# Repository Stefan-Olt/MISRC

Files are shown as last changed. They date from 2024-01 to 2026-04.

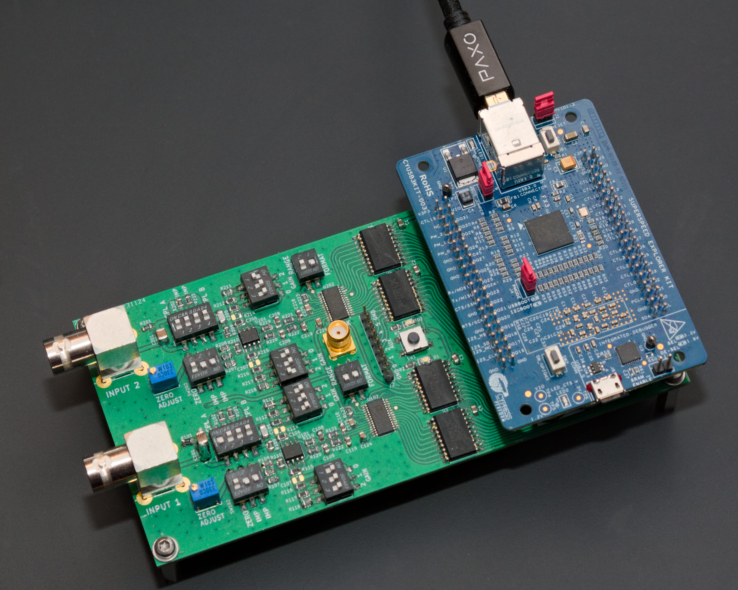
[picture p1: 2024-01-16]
assets/hardware-images/MISRC-v0.0.5-Transparent-Hand-Soldered.jpg

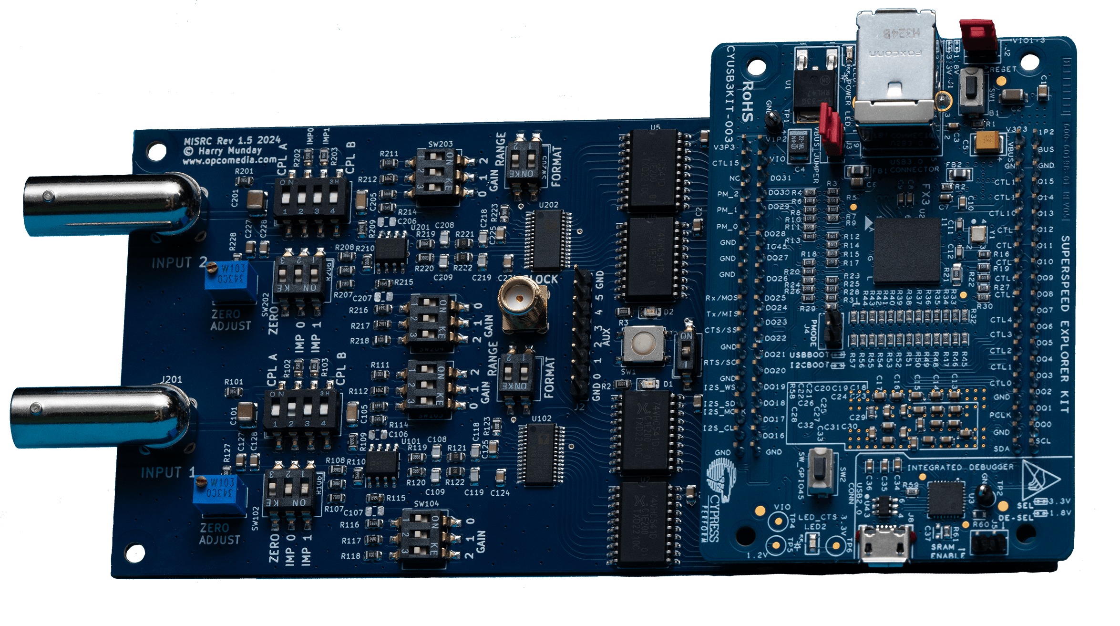
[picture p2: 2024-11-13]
assets/hardware-images/MISRC_v1.5_Sony_ILCE-7RM3_2024.06.07_14.30.14-Small.png

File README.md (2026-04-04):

# MISRC - Multi Input Simultaneous Raw RF Capture

[Hardware](#hardware-features) - [Firmware](#firmware-tang-nano-20k) - [Software](#software) - [Usage example](#capture--usage-example)

<picture>

</picture>

> V1.5 with Tang Nano 20k on the FX3 to Tang Nano 20k adaptor PCB. 

## Description

MISRC is a device to capture two signals at 12-bit and up to 40 MSPS (20 Mhz bandwith) (This could be extended to 80 MSPS in the future) and an additional 8-bit's (2-bit's for v2.5) of binary (auxiliary data) over USB 3.0.

It is intended to capture modulated tape deck RF for software demodulation, but also baseband CVBS/S-Video (Composite) video signals for software decoding, and can be used as a direct stream Oscilloscope but limited to 2vpp input voltage.

The Decode Projects:

- [VHS-Decode](https://github.com/oyvindln/vhs-decode/)
- [HiFi-Decode](https://github.com/oyvindln/vhs-decode/wiki/hifi-decode)
- [CVBS-Decode](https://github.com/oyvindln/vhs-decode/wiki/CVBS-Composite-Decode) 

Provide decoding for a wide range of videotape formats, HiFi audio and even RAW or Baseband composite decoding with free and powerful software time base correction with full post filtering control over the signal processing.

-----------

| Media RF Type | MISRC Support |
| --- | --- |
| Video FM RF | Yes |
| HiFi FM RF | Yes |
| CVBS RF | Yes |
| S-Video RF | Yes |

Possible capture examples:

- Capture 2x CVBS
- Capture 1x S-Video (Y & C)
- Capture Video RF and HiFi RF simultaneously
- Capture Video RF and CVBS simultaneously
- Capture 4ch of 24-bit 48khz audio with AUX pins via integrated or external clock-locked ADCs

> [!NOTE]
> It may be useful for other purposes as well, as it is built as a generic ADC with configurable filtering.

## Hardware features

- Dual ADC / Dual Input (BNC Connectors)
- 6 Extra Aux inputs for audio ADC modules etc
- Two 12-bit 40msps ADCs: [AD9235](https://www.analog.com/media/en/technical-documentation/data-sheets/AD9235.pdf)
- Selectable input gain (8 steps) (using [AD8138](https://www.analog.com/media/en/technical-documentation/data-sheets/ad8138.pdf) op-amp)
- Selectable ADC range (1V or 2V)
- Selectable input impedance (75, 50, 37.5 and 30 ohms)
- DC or AC (pre- or post-termination) coupling
- Zero-adjust to compensate DC offset
- Latching clipping indicator (automatic resetting on v2.5) 
- Clock source selectable: USB PLL (FX3 setup), crystal or external
- Clock output SMA for external devices (In/Out for V2.5)
- Melted PCB Traces

## Costs

> [!TIP]  
> You can support the development and production of the MISRC platform [here](https://github.com/Stefan-Olt/MISRC/wiki/Donations).
- PCB: 20-30USD
- Parts 100-150USD
- Single unit total production cost is currently 260-300USD.
- [Order a V1.5 Development MISRC](https://github.com/Stefan-Olt/MISRC/wiki/Fabrication)

------

> [!NOTE]  
> These are off-shelf PCBs and USB 3.0 devices that you add to the MISRC PCB.

- [Tang Nano 20k](https://s.click.aliexpress.com/e/_DcwBOX3) - buffer / data output over HDMI.
- [MS2130](http://en.macrosilicon.com/info.asp?base_id=2&third_id=75) - [Order Link 1](https://s.click.aliexpress.com/e/_DBaBiOp) / [Order Link 2](https://s.click.aliexpress.com/e/_okDl2Vf) - HDMI raw data stream capture.

> [!TIP]  
> You can order pre-made [adaptor PCBs here](https://ko-fi.com/s/617b72ab2c) for V1.5 boards with the headders for the FX3.  

## Firmware (Tang Nano 20k)

To be able to use the [Tang Nano 20k](https://s.click.aliexpress.com/e/_DcwBOX3) to send data over HDMI, it needs to be flashed once via USB connection:

<details closed>
<summary>Firmware Flashing </summary>
<br>

1. Download the firmare, see [releases](https://github.com/Stefan-Olt/MISRC/releases) for the latest version.

2. Install [openFPGALoader](https://github.com/trabucayre/openFPGALoader)

3. Connect your Tang to a USB 3.0 port via its Type-C, it will need this for 5V power after flashing, but not data from the MISRC.

   Run via terminal inside the firmware directory

       openFPGALoader -b tangnano20k -f hsdaoh_nano20k_misrc.fs

You have flashed your Tang Nano 20k! 

</details>

## Software

Supported operating systems with direct links to the latest release (also available on the [releases tab](https://github.com/Stefan-Olt/MISRC/releases)):

| Operating System  | Minimum supported OS version | Download x86_64 (Intel / AMD) | Download arm64 (Apple Silicon / aarch64) |
| --- | --- | --- | --- |
| Microsoft Windows | 10 (1803) | [misrc_tools-0.5.1-win-x86_64.zip](https://github.com/Stefan-Olt/MISRC/releases/download/misrc_tools-0.5.1/misrc_tools-0.5.1-win-x86_64.zip) | [misrc_tools-0.5.1-win-arm64.zip](https://github.com/Stefan-Olt/MISRC/releases/download/misrc_tools-0.5.1/misrc_tools-0.5.1-win-arm64.zip) |
| Apple macOS | 10.15 | [misrc_tools-0.5.1-macos-intel-x86_64.tar.gz](https://github.com/Stefan-Olt/MISRC/releases/download/misrc_tools-0.5.1/misrc_tools-0.5.1-macos-intel-x86_64.tar.gz) | [misrc_tools-0.5.1-macos-apple-silicon-arm64.tar.gz](https://github.com/Stefan-Olt/MISRC/releases/download/misrc_tools-0.5.1/misrc_tools-0.5.1-macos-apple-silicon-arm64.tar.gz) |
| Linux | libc6 2.35 (Ubuntu 22.04) | [misrc_tools-0.5.1-linux-x86_64.tar.gz](https://github.com/Stefan-Olt/MISRC/releases/download/misrc_tools-0.5.1/misrc_tools-0.5.1-linux-x86_64.tar.gz) | [misrc_tools-0.5.1-linux-arm64.tar.gz](https://github.com/Stefan-Olt/MISRC/releases/download/misrc_tools-0.5.1/misrc_tools-0.5.1-linux-arm64.tar.gz) |

> [!NOTE]  
> The arm64 builds for Windows are untested and considered experimental!

The packages contain two command-line applications, `misrc_capture` and `misrc_extract`. For detailed usage information see the [misrc_tools readme](/misrc_tools/README.md) and the [usage example](#capture--usage-example) down below.

If you want to build the tools yourself, see the instructions in the [misrc_tools readme](/misrc_tools/README.md).

<details closed>
<summary>Install Windows</summary>
<br>

For `misrc_capture` to be able to access the MS2130 capture device, you need to install a special driver:

Firstly download [Zadig](https://zadig.akeo.ie/)

Force the installation of `WinUSB (v6.1.7600.16385)` or `libusb-win32 (v1.2.6.0)` driver on your MS2130/MS2131 adapter, on `interface 0` leave `interface 4` alone. 

```
Interface 0 - USB Video
Interface 4 - HIDDevice
```

</details>

<details closed>
<summary>Install macOS</summary>
<br>

For macOS you do not need to install anything.

- macOS versions 10.15 and 11: You can directly execute `misrc_capture`.
- macOS 12 and later: You have to run `misrc_capture` as root (sudo). This is a new security feature by Apple, there is currently no way to bypass it. 

</details>

<details closed>
<summary>Install Linux</summary>
<br>

If you want to run `misrc_capture` as root, there is no need to install anything on Linux.

But for `misrc_capture` to be able to access the MS2130 capture device without root privilege (sudo), you need to install a udev-rule and add the user that will use `misrc_capture` to the `plugdev`-group.
The pre-build packages contains the script `install-udev-rules.sh`. On execution (double-click the file or run `./install-udev-rules.sh` on the command line) it will install the rule and add the current user to the plugdev group.

</details>

## Capture / Usage example

> [!TIP]  
> Pre-built Binaries is available on the [releases tab](https://github.com/Stefan-Olt/MISRC/releases).

`misrc_capture` is a simple command line interface program to capture from MISRC boards using [hsdaoh](https://github.com/Stefan-Olt/hsdaoh) to which leverages data capture over HDMI with [MS2130](https://s.click.aliexpress.com/e/_DBaBiOp) "U3" cheep HDMI capture cards that have YUV support and full-frame signal acesses. 

Create a folder which you wish to capture inside, open it inside terminal and then run `misrc_capture`.

Example with FLAC compression:
    
    misrc_capture -p -f -l 8 -a video_rf.flac -b hifi_rf.flac 

Example RAW:

    misrc_capture -a video_rf.s16 -b hifi_rf.s16

Example with AUX pins capture ([PCM1802 audio example](https://github.com/Stefan-Olt/MISRC/wiki/PCM-Extract))

    misrc_capture -p -f -l 8 -a video_rf.flac -b hifi_rf.flac -x pcm1802.bin

You can also define its directory path of each RF stream manually: 

    misrc_capture -p -f -l 8 -a /mnt/my_video_storrage/video_rf.flac -b ../../this/is/a/relative/path/hifi_rf.flac

Press <kbd>Ctrl</kbd>+<kbd>C</kbd> to copy and <kbd>Ctrl</kbd>+<kbd>P</kbd> to past your config from a notepad or txt file.

Use <kbd><</kbd>+<kbd>></kbd> to move edit position on the command line to edit the name or command while in terminal and <kbd>Enter</kbd> to run the command.

<kbd>Ctrl</kbd>+<kbd>C</kbd> Will kill the current process, use this to stop the capture manually.

<details closed>

<summary>Usage Arguments:</summary>
<br>

Example:

    misrc_capture -p -f -l 8 -a video_rf.flac -b hifi_rf.flac -x baseband_audio.bin

Usage:

- `-d` device_index (default: 0) (select target MS21xx device for capture)
- `-n` number of samples to read (default: 0, infinite)
- `-t` time to capture (seconds, m:s or h:m:s; -n takes priority, assumes 40msps)
- `-w` overwrite any files without asking
- `-a` ADC A output file (use '-' to write on stdout)  
- `-b` ADC B output file (use '-' to write on stdout)  
- `-x` AUX output file (use '-' to write on stdout)  
- `-r` RAW 32-Bit data output file (use '-' to write on stdout)  
- `-p` pad lower 4 bits of 16 bit output with 0 instead of upper 4
- `-A` suppress clipping messages for ADC A (need to specify -a or -r as well)
- `-B` suppress clipping messages for ADC B (need to specify -a or -r as well)
- `-f` compress ADC output as FLAC  
- `-l` LEVEL set flac compression level (default: 1) 
- `-v` enable verification of flac encoder output  
- `-c` number of flac encoding threads per file (default: auto)

</details>

## Setting Up the MISRC

- Connect your 5V USB-C to the Tang Nano for power. 

- Connect your HDMI cable (copper or fibre) to your Tang Nano for data output to the MS2130 or MS2131. 

- Connect the desired sources to the BNC inputs and select suitable impedance and AC or DC coupling.

> [!NOTE]
> You will want to use 2vpp range rather than 1vpp range to make use of the 12-bits range.

Install [OCENAudio](https://www.ocenaudio.com/) or alternatives like [Audacity](https://www.audacityteam.org/download/) it will see captures as a `40khz 16-bit` file.

Run a 3-second test capture in FLAC, to be automatically reloaded for viewing. 

    misrc_capture -p -f -B -t 3 -a test.flac

Start the capturing process for setting the DC offset then gain:
    
    - Reset clipping LEDs (always on after start or major adjustment) 
    - Increase gain during capture until clipping LED lights up
    - Decrease gain one step and reset clipping LED
    - Repeat for the second channel if in use.

- Stop capture and verify levels are acceptable in your audio DAW and the signal is centred.

Once happy, then do a full test capture to verify. 

> [!CAUTION]
> - NEVER use USB for any other heavy-load task (like external HDD/SSD drives, USB network adaptors, YUV capture devices) during capture. 
> - Do not connect/disconnect any other USB device during capture, a dedicated USB 3.0 to 3.2 Gen 2 card is ideal for dedicated capture stations as it ensures dedicated bandwidth/power if you have other items that require USB.

## Design

MISRC is loosely based on the [Domesday Duplicator (DdD)](https://github.com/simoninns/DomesdayDuplicator) a LaserDisc focused ([ld-decode](https://github.com/happycube/ld-decode)) FM RF Archival device. 

It is built around the AD9235 analogue to digital converter by Analog Devices and is heavily based on the evaluation board circuit given in its datasheet with the AD8138 Op-Amp providing adjustable fixed gain.

The MISRC like the DdD it originally used the [Cypress FX3 SuperSpeed Explorer board](https://www.infineon.com/cms/en/product/evaluation-boards/cyusb3kit-003/) for a USB 3.0 data connection, and using Sigronk for capture, with hopes to not use the DE0 FPGA, this ended with the adoption of the Tang Nano 20k and MS2130 "data over YUV" method being used. 

## License

The hardware, firmware and software is released under different open-source licenses.
You can read the [License here](https://github.com/Stefan-Olt/MISRC/wiki/Licenses)

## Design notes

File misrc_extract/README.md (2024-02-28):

# MISRC extract

Tool to extract the two ADC channels and the AUX data from the raw capture.

## Description

The 2 ADC channels with 12 bit each and the 8 bit AUX data is interleaved into 32 bit words.
This tool will deinterleave the data. For x86_64 (64 bit AMD and Intel processors)
there is handwritten assembly for higher performance using SSE instructions.

## Building

### Linux, macOS, BSD etc.

```
mkdir build
cd build
cmake ..
make
make install
```

### Windows

TBD

## Usage

* Run tool without arguments to see options

## Version History

* 0.3.1
    * Fix: incorrect align could lead to crash (fix by namazso)

* 0.3
    * New: allow extraction of data from single channel capture

* 0.2
    * Fix: signal now with correct polarity
    * Mod: output program name and version
    * New: option to pad lower 4 bits instead of upper 4

* 0.1
    * Initial Release

## License

This project is licensed under the GNU General Public License v3 or later - see the LICENSE file for details

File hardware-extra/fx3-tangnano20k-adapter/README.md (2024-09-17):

# FX3 to Tang Nano 20K Adapter

Passive adapter to use a Tang Nano 20K on MISRC that is designed to connect to a FX3 board.

## Revision 0.0.1
* First hardware build

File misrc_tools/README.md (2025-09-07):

# MISRC tools

## misrc_capture

Tool to capture, extract and compress data from the HDMI input of MS2130 using hsdaoh.

### Description

A MISRC `1.x/2.x` (with Tang Nano 20k setup) will pack the data into an HDMI signal for the MS2130.

`misrc_capture` will disable any procssing on the MS2130 and capture the data using hsdaoh. The data is unpacked in realtime and can be outputted directly into two separate files for the ADCs and a file for the aux data.
For x86_64 (64 bit AMD and Intel processors) there is handwritten assembly for higher performance using SSE instructions.

### Usage

- Run tools without arguments to see all options

Example:

    misrc_capture -p -f -l 8 -a video_rf.flac -b hifi_rf.flac -x aux_baseband_audio.bin

Usage:

- `-d` device_index (default: 0) (select target MS21xx device for capture)
- `-n` number of samples to read (default: 0, infinite)
- `-t` time to capture (seconds, m:s or h:m:s; -n takes priority, assumes 40msps)
- `-w` overwrite any files without asking
- `-a` ADC A output file (use '-' to write on stdout)  
- `-b` ADC B output file (use '-' to write on stdout)  
- `-x` AUX output file (use '-' to write on stdout)  
- `-r` RAW 32-Bit data output file (use '-' to write on stdout)  
- `-p` pad lower 4 bits of 16 bit output with 0 instead of upper 4
- `-A` suppress clipping messages for ADC A (need to specify -a or -r as well)
- `-B` suppress clipping messages for ADC B (need to specify -a or -r as well)
- `-f` compress ADC output as FLAC  
- `-l` LEVEL set flac compression level (default: 1) 
- `-v` enable verification of flac encoder output  
- `-c` number of flac encoding threads per file (default: auto)

## misrc_extract

A simple program for extracting captured raw data into separate files.

### Description

The MISRC has 2 ADC channels with 12-bit's each and the 8-bit's of AUX data is also interleaved into a total of 32 bit words.

This tool will deinterleave the data. 

### Usage

Example:

    misrc_extract -i raw_32-bit_dump.bin -p -a channel_1.s16 -b channel_2.s16 -x aux_data.bin

- `-i` Input file (use '-' to read from stdin)  
- `-a` ADC A output file (use '-' to write on stdout)  
- `-b` ADC B output file (use '-' to write on stdout)  
- `-x` AUX output file (use '-' to write on stdout)  
- `-p` pad lower 4 bits of 16 bit output with 0 instead of upper 4  
- `-s` input is captured as single channel (-b cannot be used)  

## Version History

* 0.5.1
    * Fix: build issue with FFmpeg caused builds without resampling

* 0.5
    * Fix: only capturing AUX, but no RF caused crash
    * Fix: overwrite question would only work for first file
    * New: RF can now be resampled by misrc_capture, resulting in smaller files and faster processing when only a smaller bandwidth is needed
    * New: initial audio support for the upcoming MISRC v2.5

* 0.4
    * Release of new tool: misrc_capture for direct capture from HDMI/MS2130 using hsdaoh
    * Builds for Linux, macOS and Windows (x86_64 and arm64 on all platforms)

* 0.3.1
    * Fix: incorrect align could lead to crash (fix by namazso)

* 0.3
    * New: allow extraction of data from single channel capture
      (Cypress FX3 setup)

* 0.2
    * Fix: signal now with correct polarity
    * Mod: output program name and version
    * New: option to pad lower 4 bits instead of upper 4

* 0.1
    * Initial Release

## Building / Compilation

### Required build tools

- A somewhat modern C compiler
- git (for manual compilation)
- curl (for automatic build script)
- cmake
- nasm (for x86_64 platform)
- meson/ninja (for static builds/automatic compilation)

Installation of build tools:
- macOS using [brew](https://brew.sh/): 

      brew install git curl cmake nasm meson ninja

- Linux (Debian, Ubuntu, Mint) using apt: 

      apt install build-essential git curl cmake nasm meson ninja-build

- Windows (msys2/UCRT64) using pacman: 

      pacman -S git curl mingw-w64-ucrt-x86_64-gcc mingw-w64-ucrt-x86_64-pkg-config mingw-w64-ucrt-x86_64-cmake mingw-w64-ucrt-x86_64-nasm mingw-w64-ucrt-x86_64-meson mingw-w64-ucrt-x86_64-ninja

### Automatic compilation
The script `build/build-static.sh` can be used for bulding a statically linked version.
It will download and compile dependencies. It is used to build the binaries downloadable here.
In case it doesn't work for your needs you can compile misrc_tools manually.

### Dependencies
- [libusb](https://github.com/libusb/libusb)
- [libuvc](https://github.com/libuvc/libuvc) (for Windows cmake fixes use [Steve-m's fork](https://github.com/steve-m/libuvc))
- [hsdaoh](https://github.com/Stefan-Olt/hsdaoh) (the main hsdaoh branch (steve-m) does not have required changes merged, use the linked one!)
- [FLAC](https://github.com/xiph/flac) (optional, v1.5.0 and newer required for multi-threading support)

Installation of FLAC, libusb and libuvc (if available):

- macOS using [brew](https://brew.sh/): 

      brew install flac libusb

- Linux (Debian, Ubuntu, Mint) using apt: 

      apt install libflac-dev libusb-1.0-0-dev libuvc-dev

- Windows (msys2/UCRT64) using pacman: 

      pacman -S mingw-w64-ucrt-x86_64-flac mingw-w64-ucrt-x86_64-libusb

## Manual Build Process

1. Build libuvc (required on Windows and macOS):
   <details closed>
   <summary>macOS (Linux, BSD...)</summary>
   
   ```
   git clone https://github.com/libuvc/libuvc.git
   mkdir libuvc/build && cd libuvc/build
   cmake ../
   make
   sudo make install
   ```
   
   </details>
   <details closed>
   <summary>Windows</summary>
   
   ```
   git clone https://github.com/steve-m/libuvc.git
   mkdir libuvc/build && cd libuvc/build
   cmake ../ -DCMAKE_INSTALL_PREFIX:PATH=/mingw64
   cmake --build .
   cmake --install .
   ```
   
   </details>

2. Build hsdaoh
   <details closed>
   <summary>Linux, macOS, BSD...</summary>
   
   ```
   git clone https://github.com/Stefan-Olt/hsdaoh.git
   mkdir hsdaoh/build
   cd hsdaoh/build
   cmake ../ -DINSTALL_UDEV_RULES=ON
   make
   sudo make install
   sudo ldconfig
   ```
   
   </details>
   <details closed>
   <summary>Windows</summary>
   
   ```
   git clone https://github.com/Stefan-Olt/hsdaoh.git
   mkdir hsdaoh/build && cd hsdaoh/build
   cmake ../ -DCMAKE_INSTALL_PREFIX:PATH=/mingw64
   cmake --build .
   cmake --install .
   ```
   
   </details>

3. Build misrc_tools
   <details closed>
   <summary>Linux, macOS, BSD...</summary>
   
   ```
   git clone https://github.com/Stefan-Olt/MISRC.git
   cd ./MISRC/misrc_tools
   mkdir build
   cd build
   cmake ../
   make
   sudo make install
   ```
   
   </details>
   <details closed>
   <summary>Windows</summary>
   
   ```
   git clone https://github.com/Stefan-Olt/MISRC.git
   cd ./MISRC/misrc_tools
   mkdir build
   cd build
   cmake ../ -DCMAKE_INSTALL_PREFIX:PATH=/mingw64
   cmake --build .
   cmake --install .
   ```
   
   </details>

## License

This project is licensed under the GNU General Public License v3 or later - see the LICENSE file for details.

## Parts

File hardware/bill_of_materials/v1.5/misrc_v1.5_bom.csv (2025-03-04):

Designator | Qty | Value | Package/Footprint | Type | Manufacturer Part Number | BOM Notes | Notes
C1, C12, C13, C2, C20, C21, C22, C23, C24, C29, C3, C30, C31, C4, C5, C7 | 16 | 1µf | C_0805_2012Metric | SMD | KGM21AR71H105KU | Exact Part Not Required
C10, C17, C18, C11, C16, C19, C6 | 7 | 470µf | CP_Radial_Flat_D8.0mm_P3.50mm | THT | UHV1C471MPD | Exact Part Not Required | Lay Flat, Not Vertical for pin headder clearence.
C101, C201 | 2 | 100µf | C_1210_3225Metric | SMD | EMK325ABJ107MM-T | Exact Part Not Required
C102, C110, C117, C202, C210, C217 | 6 | 10µf | C_1210_3225Metric | SMD | CA45-A-16V-10μF-K（C185774) | Exact Part Not Required
C103, C112, C113, C115, C120, C122, C123, C124, C125, C126, C14, C15, C203, C212, C213, C215, C220, C222, C223, C224, C225, C226, C26, C9 | 24 | 100nf | C_0805_2012Metric | SMD | C0805C104K4RACTU | Exact Part Not Required
C104, C111, C114, C116, C121, C128, C204, C211, C214, C216, C221, C228, C27 | 13 | 1nf | C_0805_2012Metric | SMD | C0805C102J5GACTU | Exact Part Not Required
C105, C205 | 2 | 470nf | C_1206_3216Metric | SMD | CC1206KKX7R9BB474 | Exact Part Not Required
C106, C107, C206, C207 | 4 | 1pf | C_0805_2012Metric | SMD | C0805C109C2GACTU | Exact Part Not Required | DNP
C108, C109, C208, C209 | 4 | 82pf | C_0805_2012Metric | SMD | C0805C820J5GACTU | Exact Part Not Required
C118, C119, C218, C219 | 4 | 15pf | C_0805_2012Metric | SMD | C0805X150J5GACTU | Exact Part Not Required
C127, C227, C25, C28, C8 | 5 | 10µf | C_0805_2012Metric | SMD | C0805C106J8RACAUTO | Exact Part Not Required
D1, D2 | 2 | LED | LED_0805_2012Metric | SMD | APT2012SECK/J4-PRV | Exact Part Not Required
J1 | 1 | SMA | SMA_Vertical | THT | BWSMA-KE-Z001 | Exact Part Not Required | https://m.tb.cn/h.5G8UUMPs4BD5jl0?tk=fbloW9FPomB
J101, J201 | 2 | BNC | BNC Socket Right-Angle DOSIN | THT | DOSIN-801-0050_C521210 | Exact Part Not Required
J2 | 1 | Conn_01x08_Socket | PinHeader_1x08_P2.54mm_Vertical | THT | 61300811121 | Exact Part Not Required
J3 | 1 | GPIFII_J6 | PinHeader_2x20_P2.54mm_Vertical | THT | 61302021121 | Exact Part Not Required | Ensure 2x20 2.54mm headder
J4 | 1 | GPIFII_J7 | PinHeader_2x20_P2.54mm_Vertical | THT | 61302021121 | Exact Part Not Required | Ensure 2x20 2.54mm headder
L1, L2 | 2 | 100µ | L_Bourns-SRU8043 | SMD | SRU8043-101Y | Exact Part Not Required
Q1 | 1 | Bipolar (BJT) Single Transistor | SOT-223-3_TabPin2 | SMD | FZT690B | Use Exact Value Yes
Q101, Q102, Q201, Q202 | 4 | Bipolar Transistor | SOT-23-3 | SMD | CMPT5179-TR-PBFREE | Use Exact Value Yes
Q2 | 1 | Bipolar (BJT) Transistor PNP | SOT-223-3_TabPin2 | SMD | FZT790A | Use Exact Value Yes
R1, R123, R126, R223, R226 | 5 | 10kohm | R_0805_2012Metric | SMD | SDR10EZPF1002 | Exact Part Not Required
R101, R102, R107, R201, R202, R207 | 6 | 75ohm | R_0805_2012Metric | SMD | CRCW080575R0FKEAHP | Exact Part Not Required
R103, R203 | 2 | 150ohm | R_0805_2012Metric | SMD | AC0805FR-7W150RL | Exact Part Not Required
R104, R105, R111, R118, R204, R205, R211, R218, R4, R5 | 10 | 1kohm | R_0805_2012Metric | SMD | RCC08051K00FKEA | Exact Part Not Required
R106, R108, R206, R208 | 4 | 39ohm | R_0805_2012Metric | SMD | WF08P39R0FTL | Exact Part Not Required
R109, R110, R209, R210 | 4 | 499ohm | R_0805_2012Metric | SMD | MCU0805PD4990DP500 | Exact Part Not Required
R112, R117, R212, R217 | 4 | 2k49 | R_0805_2012Metric | SMD | ERA6AEB2491V | Exact Part Not Required
R113, R116, R124, R213, R216, R224 | 6 | 4k99 | R_0805_2012Metric | SMD | CRCW08054K99FKEAHP | Exact Part Not Required
R114, R115, R214, R215 | 4 | 6k49 | R_0805_2012Metric | SMD | ERJ-PB6B6491V | Exact Part Not Required
R119, R120, R219, R220 | 4 | 39ohm | R_0805_2012Metric | SMD | WF08P39R0FTL | Exact Part Not Required
R121, R122, R221, R222 | 4 | 22ohm | R_0805_2012Metric | SMD | 755-SDR10EZPF22R0 | Exact Part Not Required
R125, R127, R225, R228 | 4 | 3k3 | R_0805_2012Metric | SMD | RT0805BRD073K3L | Exact Part Not Required
R2, R3 | 2 | 100ohm | R_0805_2012Metric | SMD | ERJ-P6WF1000V | Exact Part Not Required
RV101, RV201 | 2 | 10kohm | Potentiometer_Bourns_3266W_Vertical | THT | 3266W-1-103LF | Use Exact Part Yes
SW1 | 1 | SW_Push | SW_SPST_EVQP0 | SMD | EVQ-Q2201W | Exact Part Not Required
SW101, SW201 | 2 | SW_DIP_x04 | SW_DIP_SPSTx04_Slide_6.7x11.72mm_W8.61mm_P2.54mm_LowProfile | SMD | IKD0403101 | Exact Part Not Required
SW102, SW103, SW104, SW202, SW203, SW204 | 6 | SW_DIP_x03 | SW_DIP_SPSTx03_Slide_6.7x9.18mm_W8.61mm_P2.54mm_LowProfile | SMD | A6S-3104-H | Exact Part Not Required
SW105, SW205 | 2 | SW_DIP_x02 | SW_DIP_SPSTx02_Slide_6.7x6.64mm_W8.61mm_P2.54mm_LowProfile | SMD | IKD0203101 | Exact Part Not Required
SW2 | 1 | SW_DIP_x01 | SW_DIP_SPSTx01_Slide_6.7x4.1mm_W8.61mm_P2.54mm_LowProfile | SMD | EDS01SGRSTR04Q | Exact Part Not Required
U1 | 1 | 4043 | SO-16_3.9x9.9mm_P1.27mm | SMD | HEF4043BT-Q100J | Exact Part Not Required
U101, U201 | 2 | AD8138ARZ | SO-8_3.9x4.9mm_P1.27mm | SMD | AD8138ARZ | Use Exact Part Yes | https://m.tb.cn/h.5tp5MxFBp49WPry?tk=0JIOW9FOw4B
U102, U202 | 2 | AD9235 | TSSOP-28_4.4x9.7mm_P0.65mm | SMD | AD9235BRUZ-40 | Use Exact Part Yes | -20 = 20msps / -40 = 40msps / -65 = 65msps https://m.tb.cn/h.5tW5QqMkqOTZUye?tk=rmCIW9Fmz03
U2, U3, U4, U5 | 4 | 74VHC541D,118 | SOIC-20W_7.5x12.8mm_P1.27mm | SMD | 74VHC541D,118 | Use Exact Part Yes
U6 | 1 | TPS60401 | SOT-23-5 | SMD | TPS60401DBVT | Use Exact Part Yes
U7 | 1 | ADP7156ARDZ | SOIC-8-1EP_3.9x4.9mm_P1.27mm_EP2.29x3mm | SMD | ADP7156ARDZ-3.3-R7 | Use Exact Part Yes
X1 | 1 | 40Mhz | Oscillator_SMD_EuroQuartz_XO53-4Pin_5.0x3.2mm | SMD | XO32050UITA-40.000 | Use Exact Part Yes | Alternative: OT503240MJBA4SL
PCBWay Friendly Version v1.5
Grand Total Parts: 192
Total Unique Parts: 50
Allow Substitutes yes.
Date: 15.08.2024 (DD.MM.YYYY)
Note: Mounting Holes 3.2mm M3

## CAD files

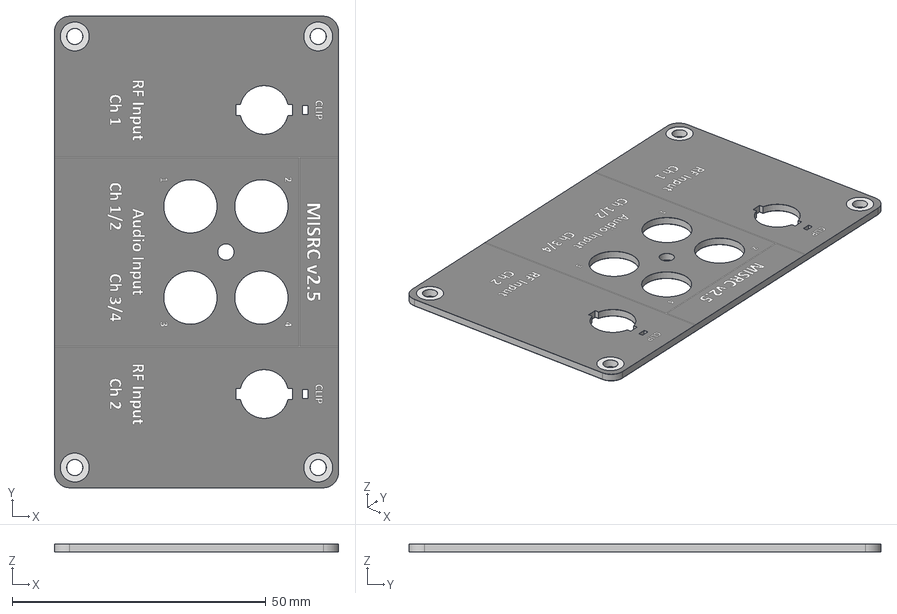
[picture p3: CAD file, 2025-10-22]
hardware/kicad/dev/3d_models/misrc_v2.5_front_panel.step
56.0 x 93.0 x 1.64 mm
misrc_v2.5_front_panel_copper
misrc_v2.5_front_panel_pad
misrc_v2.5_front_panel_silkscreen
misrc_v2.5_front_panel_soldermask x 2
misrc_v2.5_front_panel_PCB

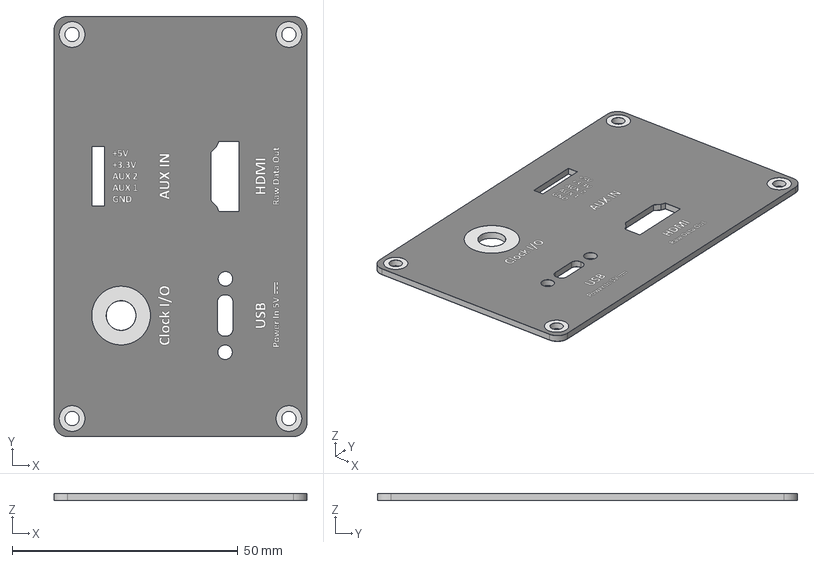
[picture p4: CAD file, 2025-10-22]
hardware/kicad/dev/3d_models/misrc_v2.5_back_panel.step
56.0 x 93.0 x 1.64 mm
misrc_v2.5_back_panel_copper
misrc_v2.5_back_panel_pad
misrc_v2.5_back_panel_silkscreen
misrc_v2.5_back_panel_soldermask x 2
misrc_v2.5_back_panel_PCB

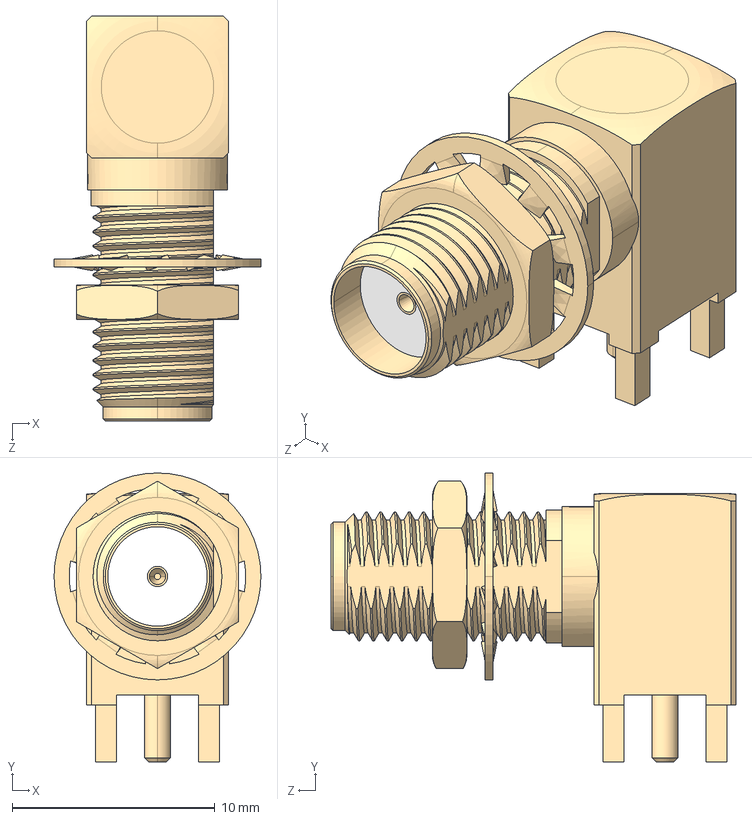
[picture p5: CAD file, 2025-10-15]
hardware/kicad/dev/3d_models/RF2-49B-T-00-50-G-HDW.STEP
10.2 x 14.2 x 20.0 mm

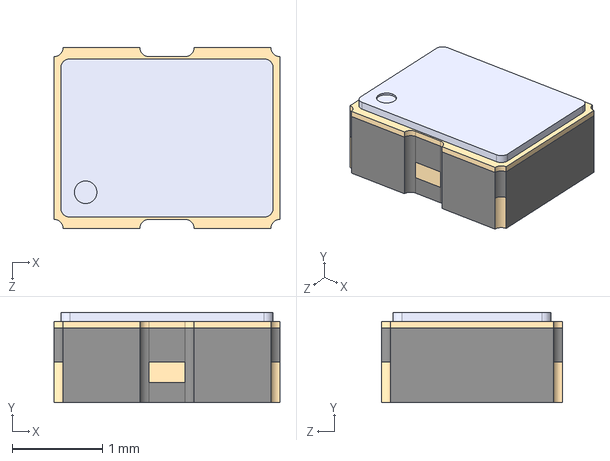
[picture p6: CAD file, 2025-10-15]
hardware/kicad/dev/3d_models/ECS-TXO-2520-33-400-AN-TR.STEP
2.50 x 1.00 x 2.00 mm

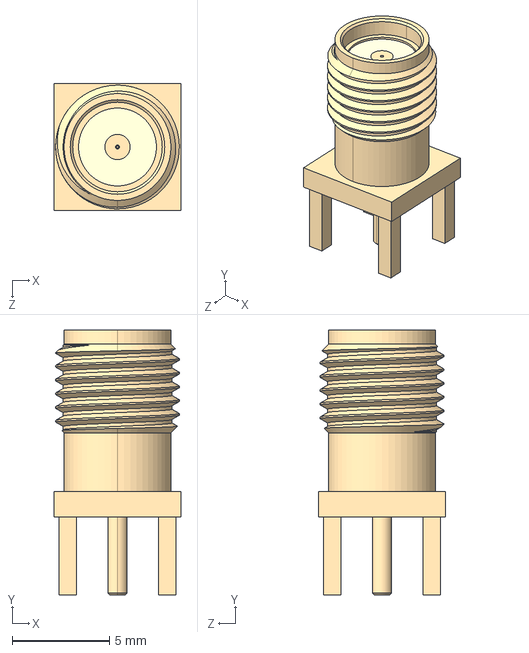
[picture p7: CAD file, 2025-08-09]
hardware/kicad/dev/3d_models/SMA_CONNECTOR.step
6.50 x 13.6 x 6.50 mm

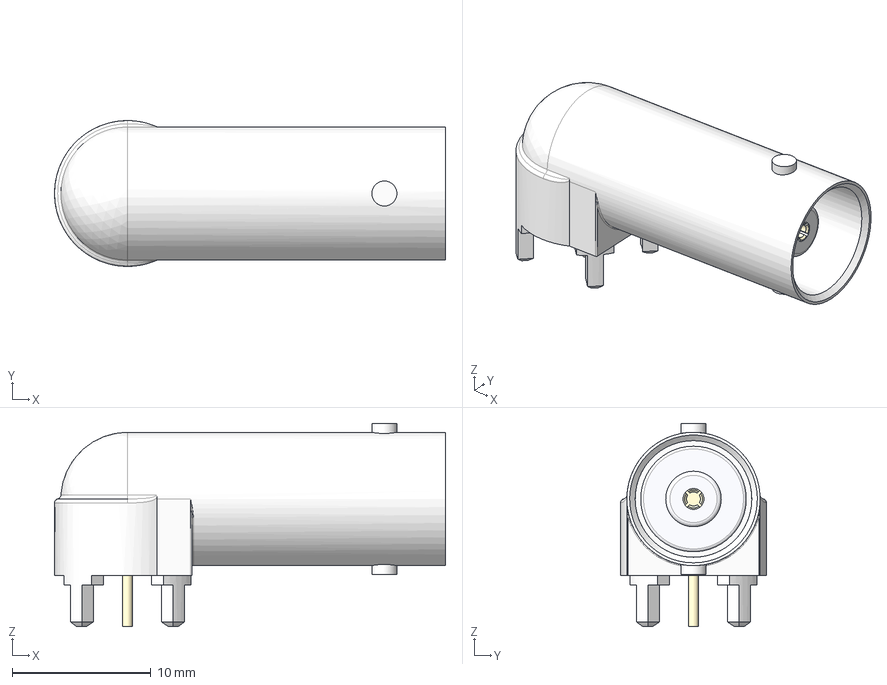
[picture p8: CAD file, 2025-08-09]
hardware/kicad/dev/3d_models/DOSIN-BNC_F102-243.stp
28.1 x 10.5 x 14.7 mm

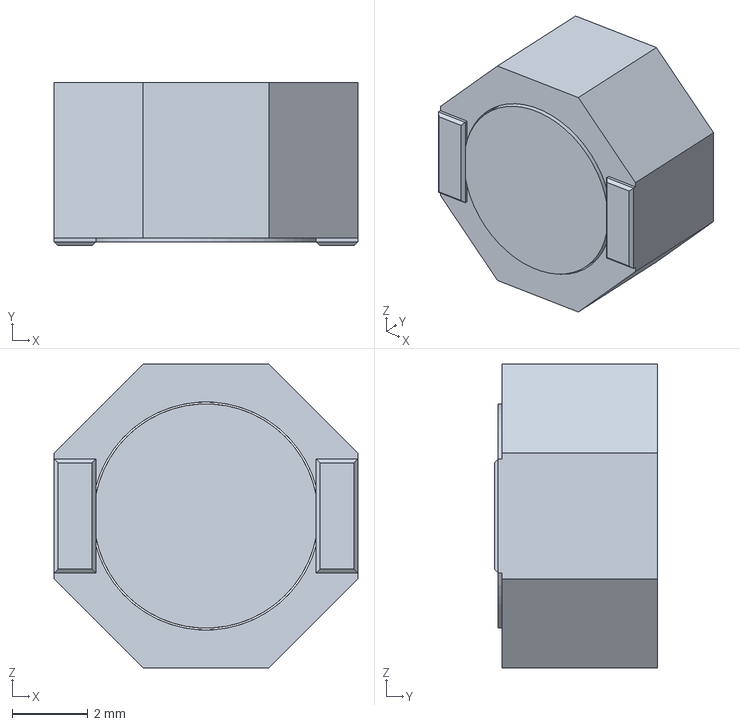
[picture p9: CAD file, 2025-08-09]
hardware/kicad/dev/3d_models/sru8043-101y.stp
8.00 x 4.30 x 8.00 mm

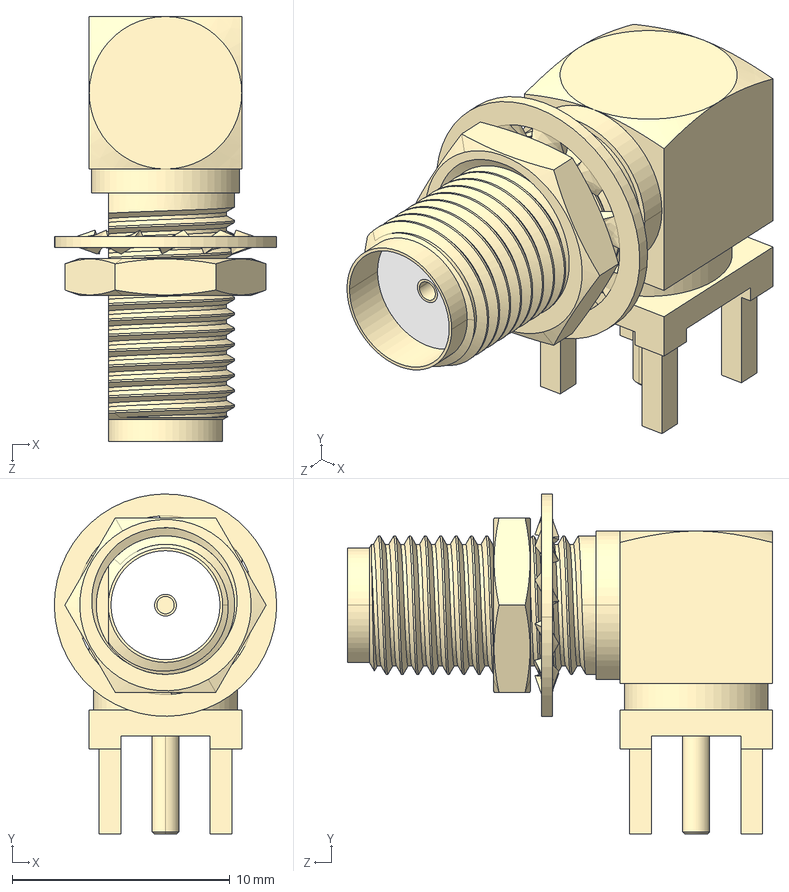
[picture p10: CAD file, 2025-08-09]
hardware/kicad/dev/3d_models/CONSMA002-L-G.step
10.2 x 15.6 x 19.5 mm
CONSMA002-L-G-body
Nut
Washer

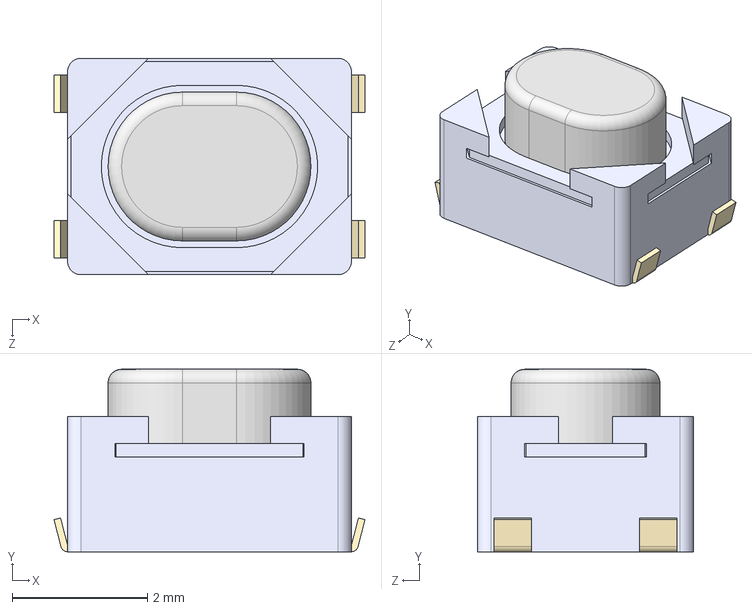
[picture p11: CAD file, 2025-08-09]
hardware/kicad/dev/3d_models/PTS810_SJM_250_SMTR_LFS.step
4.60 x 2.70 x 3.20 mm

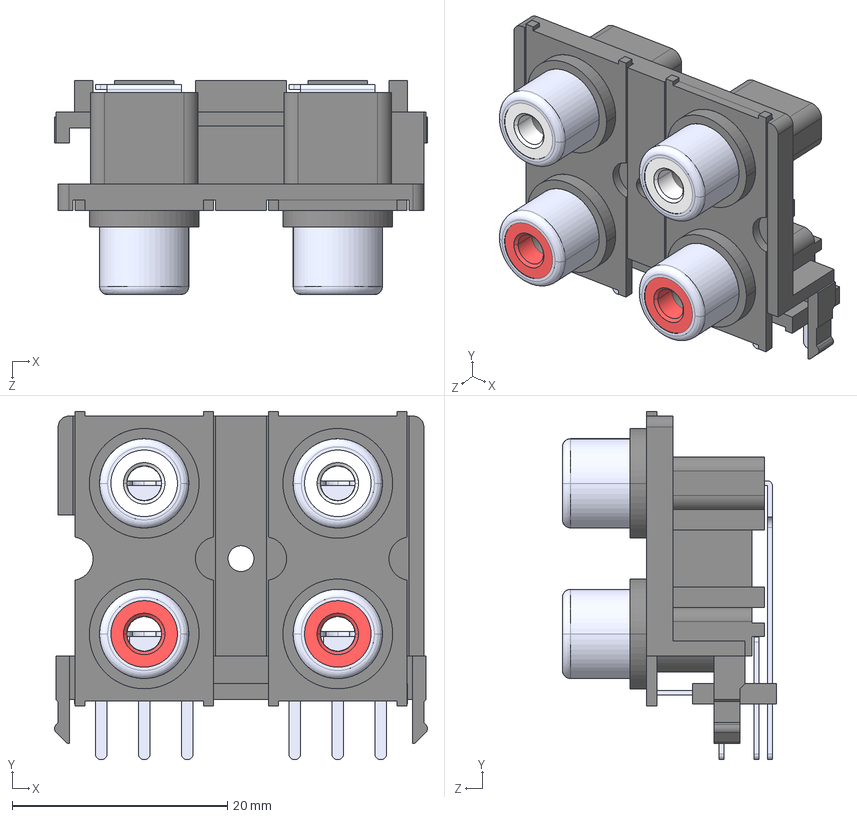
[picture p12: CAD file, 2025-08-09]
hardware/kicad/dev/3d_models/KLP42X-61-WW-RR_rA7.IGS
34.7 x 32.4 x 19.9 mm

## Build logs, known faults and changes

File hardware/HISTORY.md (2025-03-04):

# History

## Revision 0.0.5

* First hardware build

## Revision 0.0.6

* Fix: Added capacitors at output from inverting charge pump to stabilize operation
* Mod: Changed zero adjust from center voltage control to inverting input offset to allow wider adjustment range (untested)
* Mod: Changed feedback resistor 1k3 to 1k to allow lower gains (useful for CVBS capture)
* Mod: Changed selectable impedances to 75, 50, 37.5 and 30 Ohms (useful for CVBS capture)
* Mod: Increased coupling capacitor values to 100µF and 470nF (useful for CVBS capture)
* Mod: Remove copper around screw holes to avoid possible ground connection when soldermask gets scratched
* New: Added selectable crystal oscillator as clock source
* New: Added input protection with transistor zener clamp (untested)

## V1.5

Official production release version 1.0 effectively 30-50 units in the wild.

- BNC changed too much cheaper and case practical DOSIN
- Adaptor PCB developed for using the tang nank 20k and hsdaoh workflow
- 3D printable case designs
- Updated Bill of Materials

## V1.5a 

- Silkscreen cleanups 
- SMA changed to a more generic format (supporting all cables)
- Crystal package updated to a larger format, with higher load for PCM1802 boards support
- Updated Bill of Materials

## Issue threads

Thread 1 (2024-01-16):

3D Printed Cases

harrypm, 2024-01-16:
As discovered with the DdD a 3D printed or a machined case even can be invaluable for providing EMI shielding for open air board capture devices.

## Task

- [ ] Basic 3D Printed Case
- [ ] 3D Printed case expanded for Audio Board

callanrocks, 2024-11-25:
I can get one made if there is a model for the MISRC.

harrypm, 2024-11-25:
@callanrocks The dimensions can be taken from the KiCad files, mainboard +- MISRC adapter size I can get exact visual measurements tomorrow

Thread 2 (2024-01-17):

Bill of Meterials BOM / PCBway & JLC Compatiable Gerbers

harrypm, 2024-01-17:
# To Do

- [x] Bill of Materials
- [x] PCBway Gerbers
- [x] JLCPCB Gerbers

## Notes

Drill Files and solder mask layers.

Stefan-Olt, 2024-01-23:
Gerbers and BOM is added, it needs to be checked what is still required for automated assembly

dellsam34, 2024-02-04:
When this will be available?

harrypm, 2024-02-04:
@dellsam34 It already is available, if you mean when will 1-click ordering of the PCB fabricated will be available, then well that will be after Chinese newyears as all the fabs are closed currently, and the tedious BOM price adjustments are not finished, due to minimum order quantities of items like the DIP switches.

dellsam34, 2024-02-04:
Will the order include a fully assembled unit or the buyer has to tackle the manufacturing process?

harrypm, 2024-02-04:
Fully assembled main PCB, all you will have to do is just cut two pins and push on the fx3 USB board, firmware is loaded in live which makes everything very software side fire and forget configurable, but a second revision may have it all just integrated into a single PCB, a piping play device with a GUI software later down the line etc

There will be an announcement when it's available and setup docs are completely finished for end users, it's essentially the same procedure as a Domesday Duplicator but without the manually flashing 2 boards part very friendly to anyone that can read a single page guide.

That will also be a guide for manually soldering as it will still most likely be cheaper just to buy your own BNC connectors and solder than paying a fab to source the parts which considering the price of the tooling currently it's not an unreasonable thing for most people to do for THT parts 10 seconds of effort.

Closed 2024-11-10.

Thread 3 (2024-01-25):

MISRC Extract

harrypm, 2024-01-25:
Currently while capture is universal self contained extraction tools only exist for Windows.

# Self Contained Builds

- [x] Windows Build
- [x] Linux App Image
- [x] MacOS App

Stefan-Olt, 2024-01-25:
A appimage for Linux does not make any sense, because it's a command-line application, so you cannot run it like a AppImage and also it does not have any dependencies, that's what AppImages are designed for, include all dependencies. A simple binary would be more than enough. But Linux binaries are a bit tricky: You need to build them on a old machine with old libc6, because they won't run with newer libc6. But I don't think linux binaries are needed at all, because building it on Linux is really simple and the vast majority of Linux users know how to compile something.

I don't know how it's done, but I think GitHub can create Release builds. You need to setup somekind of VM, that get's started when you make a new release and it will build all Release artifacts. Not sure if that works for ARM Mac yet

harrypm, 2024-01-26:
Automated appimage builds are possible for example the [tbc-video-export](https://github.com/JuniorIsAJitterbug/tbc-video-export/releases) tool is a CLI tool but now has exe & appimage builds automated on every commit to make a new build release hands off wise, this would be ideal to setup here as well, best to talk to Jitterbug on the discord about it.

Currently the extract tool has build issues on Mint 21.3 and outputs this:

```
CMake Error at CMakeLists.txt:7 (enable_language):
  No CMAKE_ASM_NASM_COMPILER could be found.

  Tell CMake where to find the compiler by setting either the environment
  variable "ASM_NASM" or the CMake cache entry CMAKE_ASM_NASM_COMPILER to the
  full path to the compiler, or to the compiler name if it is in the PATH.
```

Stefan-Olt, 2024-01-26:
The build issue is exactly what cmake reported, you do not have nasm installed, can be solved by: `sudo apt install nasm`
nasm is only needed for building misrc_extract, not for running (it is used to assemble the hand-written assembly).
I will talk to jitterbug how to make this github actions

harrypm, 2024-01-26:
Yeah that fixed the build process, updated the wiki docs for it too.

Stefan-Olt, 2024-01-26:
Thanks to Jitterbug there are now automated builds for Linux, Windows and macOS (Intel and ARM)

Closed 2024-01-26.

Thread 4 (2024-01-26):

misrc_extract won't build on cpu architectures other than x86_64

Stefan-Olt, 2024-01-26:
A known issue in the CMakeLists.txt file is, that the assembly code is always included, even on other cpu architectures. A check needs to be added, so it is only included in x86_64 builds.
Therefore no ARM64 (no matter if Linux, Mac or Windows) are possible without editing the file at the moment (also 32-bit won't work).

Stefan-Olt, 2024-01-26:
Found a nice test routine in xiph.org/flac cmake build files

Closed 2024-01-26.

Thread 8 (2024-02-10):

Better capture tool than sigrok-cli

Stefan-Olt, 2024-02-10:
sigrok-cli has a major issue: It is a single-threaded application. That means if only once the disk is not finished writing a data packet before the next one comes in the capture is ruined. The sigrok-cli manual says one should use a ramdisk, but this is currently not an option for the vast majority of users, as usual capture sizes are significantly larger than the RAM.
I think the easiest way is to write a minimalist replacement for sigrok-cli (we do not need all the stuff that is in it, like the decoders, signal display, special output formats), that will open the device using libsigrok in one thread and write the data in another thread having a fifo or a ringbuffer in between. We could even include the extraction routine from misrc_extract (if the PC is fast enough).

I would image something like this:
```
misrc_capture --buffer-size 4G -d cypress-fx3 -s 40m -r rawfile.bin -a channel_one.s16 -b channel_two.s16
```
With samplerate and device having the shown values as default options. The entire buffer should be allocated before the capture starts, with the size being adjustable by the user (4 GB seems reasonable I think, as the average user will have at least 16GB of RAM)

harrypm, 2024-02-10:
I'm just wondering from a documentation perspective should there be a direct suggestion towards using NVME for pure safety of writing, SSDs are de facto go to either way but I'm just wondering is there a better safe margin of error due to pure speed?

Stefan-Olt, 2024-02-10:
I tried writing to NVMe SSD, same issue (I do not have a dedicated NVMe for capture, it was the one with my OS), so far capturing to my NAS is the best option (connected at 10G)

Stefan-Olt, 2024-02-10:
Correction to first idea: It seems libsigrok handles way too much for us, including the writing of the file, but we want direct access to the buffer. Better option is probably to only copy the device driver code (which is not part of sigrok anyway due to licensing issue) and use that. That also had the benefit that we had a single standalone application for capturing

Stefan-Olt, 2024-02-12:
After inspecting the driver code I think the best option is to rewrite it more or less: Make new functions and copy only small sections of code, as the driver uses a lot of sigrok-specific data structures etc.
First steps would be:

1. Create a new tool `misrc_capture`
2. Create two threads, one for capturing and one for processing/storing
3. Include libusb and open usb bus in the capture thread
4. Function to scan usb bus for fx3 device
5. Function to upload firmware to fx3

jara1, 2024-03-14:
Hi, I'm pretty sure you are aware of https://github.com/cnlohr/fx3fun. Isn't there something (API?) what could be reused to simplify creation of the capture tool?

Closed 2025-05-26.

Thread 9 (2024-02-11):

Audio Sub-Board

harrypm, 2024-02-11:
# Audio Sub-Board

This segment of the project is mandatory for having a complete single run capture chain for VHS/Betamax formats like SMPTE-C/2" Quad/Umatic only have linear audio capture so they are stuck in automation limbo without the addition of a sub-board or version with audio inputs.

This issue tracks the ideas & solutions for audio.

## Requirements

2-4 Channels with balenced/unbalenced support

For a dedicated device these connectors are suitable:

Quad TRS / Quad XLR TRS Combo - [Nutrik Connectors](https://www.neutrik.com/en/neutrik/products/xlr-connectors/xlr-chassis-connectors/combo-a-series?c=audio)

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

For a PC add-in card module style system however 6.35mm jacks are the best way to go.

## Perposed Solutions

### Pi Pico + Clock Source

- Single [PCM1802](https://www.ti.com/lit/ds/symlink/pcm1802.pdf)
- Duel [PCM1802](https://www.ti.com/lit/ds/symlink/pcm1802.pdf)

Using the current clockgen board as a foundation this would be easy to script into current CLI capture.

Namazso made a more slim down version [here](https://github.com/namazso/cxadc-clockgen-mod) which will prob be the quickest solution to capture scripted using the MISRC clock source.

## Custom Board

Using an [PCM1840](https://www.ti.com/lit/ds/symlink/pcm1840.pdf)

Using an [PCM4204](https://www.ti.com/lit/ds/symlink/pcm4204.pdf)

namazso, 2024-02-28:
I made a simple PCM extractor for PCM1802: https://github.com/namazso/pcm_extract

Just hook up one or two of the chip on the aux bits and the clock at 512fsc master mode (only MODE0 bridged) and filter the aux data through the linked program. Naturally, if you use two then run it twice, with respective arguments.

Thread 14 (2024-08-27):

Tang Nano 20K adapter board with audio

Stefan-Olt, 2024-08-27:
I would like to replace the FX3 with the an (cheap) FPGA that can stream the data over HDMI into a USB3 raw capture device as shown by  the hsdaoh (high-speed data-acquisition over HDMI) project. The FX3 never worked reliable and has a license issue that basically forces everyone to register at Infineon, download their example code, modify and compile it.

While creating the FPGA binary still requires downloading a manufacturer IDE that requires registering, there is no issue with sharing the full code or the binary. Additionally the code is somewhat cross-platform and should need only minor modifications to run on another FPGA if needed.

The Tang Nano 20K board is significantly smaller than the FX3, while it might be possible to directly integrate it into the MISRC board at some point, my first approach would be an adapter board that not only contains the header for the Tang Nano, but also an audio ADC (or maybe two for 4 channels) for capturing the audio.

Closed 2025-05-26.

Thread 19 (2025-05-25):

Windows hsdoah build fails due to GCC change

nmatsuda, 2025-05-25:
Following the build instructions for Windows fails currently because of function definitions in hsdoah that are no longer supported in GCC 15 (see https://github.com/steve-m/hsdaoh/issues/9), but this can be temporarily resolved by passing `-DCMAKE_C_STANDARD=99` to cmake.

Stefan-Olt, 2025-05-25:
It seems gcc 15 set the default C standard to C23, but in cmake I set the standard to C11, so I so I don't know the issue is, also the error message explicitly mentions that you can use C11. Can you try `-DCMAKE_C_STANDARD=11`?

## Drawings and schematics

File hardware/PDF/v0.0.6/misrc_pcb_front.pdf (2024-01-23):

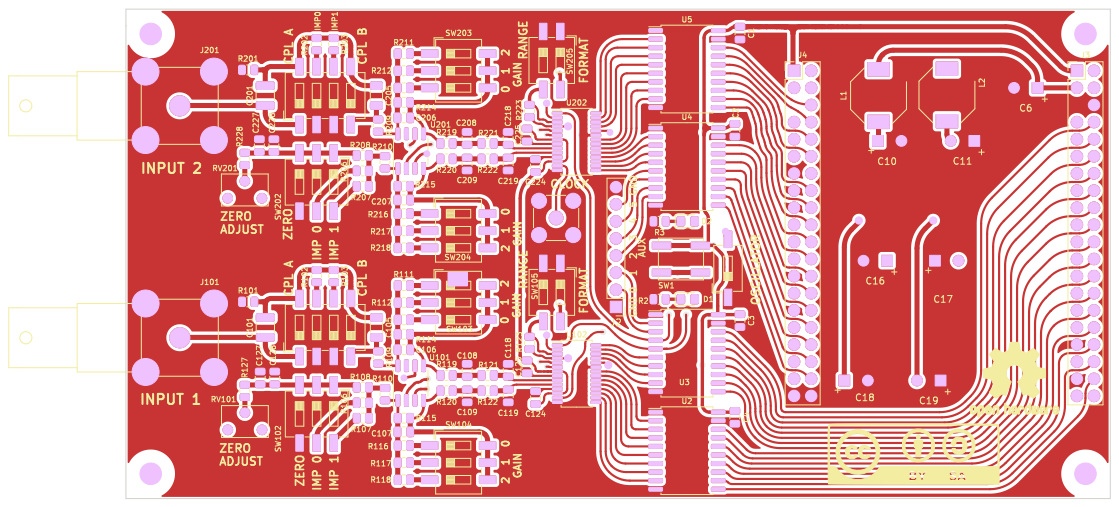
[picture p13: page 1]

4 ZERO
File: misrc.kicad_pcb Sheet: OSCILLATOR IMP 1

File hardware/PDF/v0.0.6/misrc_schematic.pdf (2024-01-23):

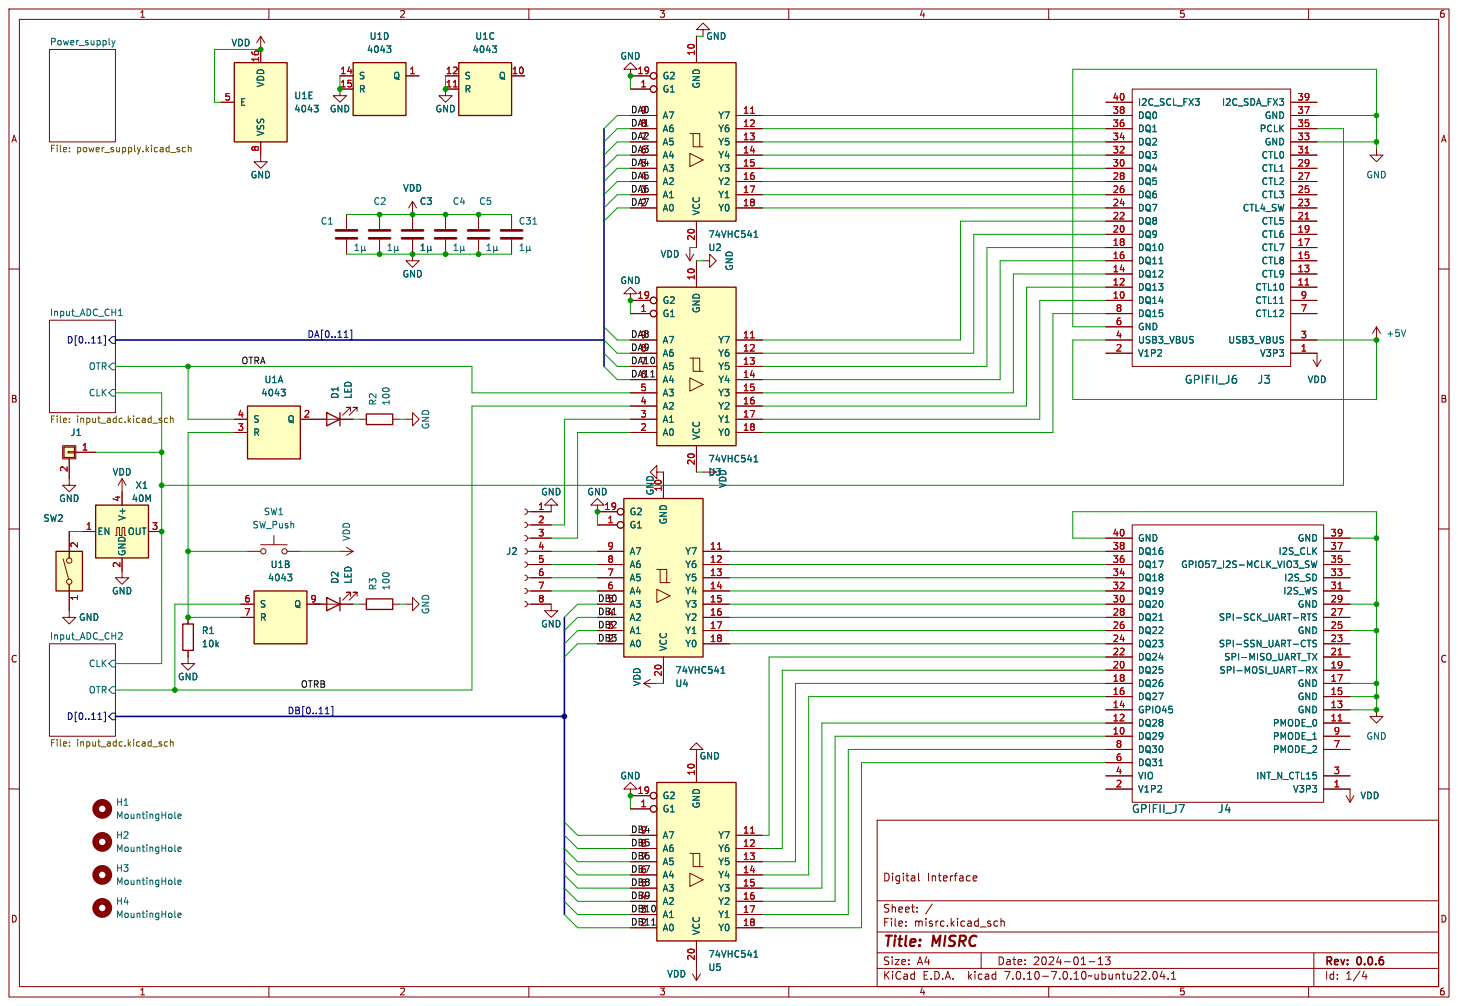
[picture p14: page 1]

2 J1 H2 MountingHole H4 MountingHole H1 MountingHole H3 MountingHole R1

File: misrc.kicad_sch Sheet: / Digital Interface D[0..11] CLK OTR

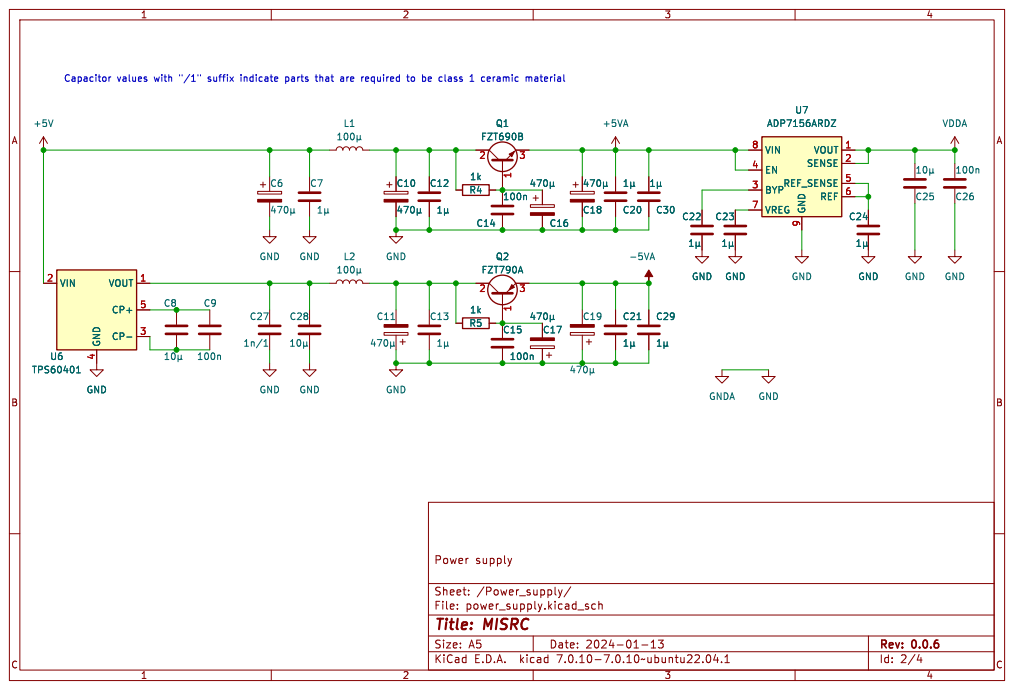
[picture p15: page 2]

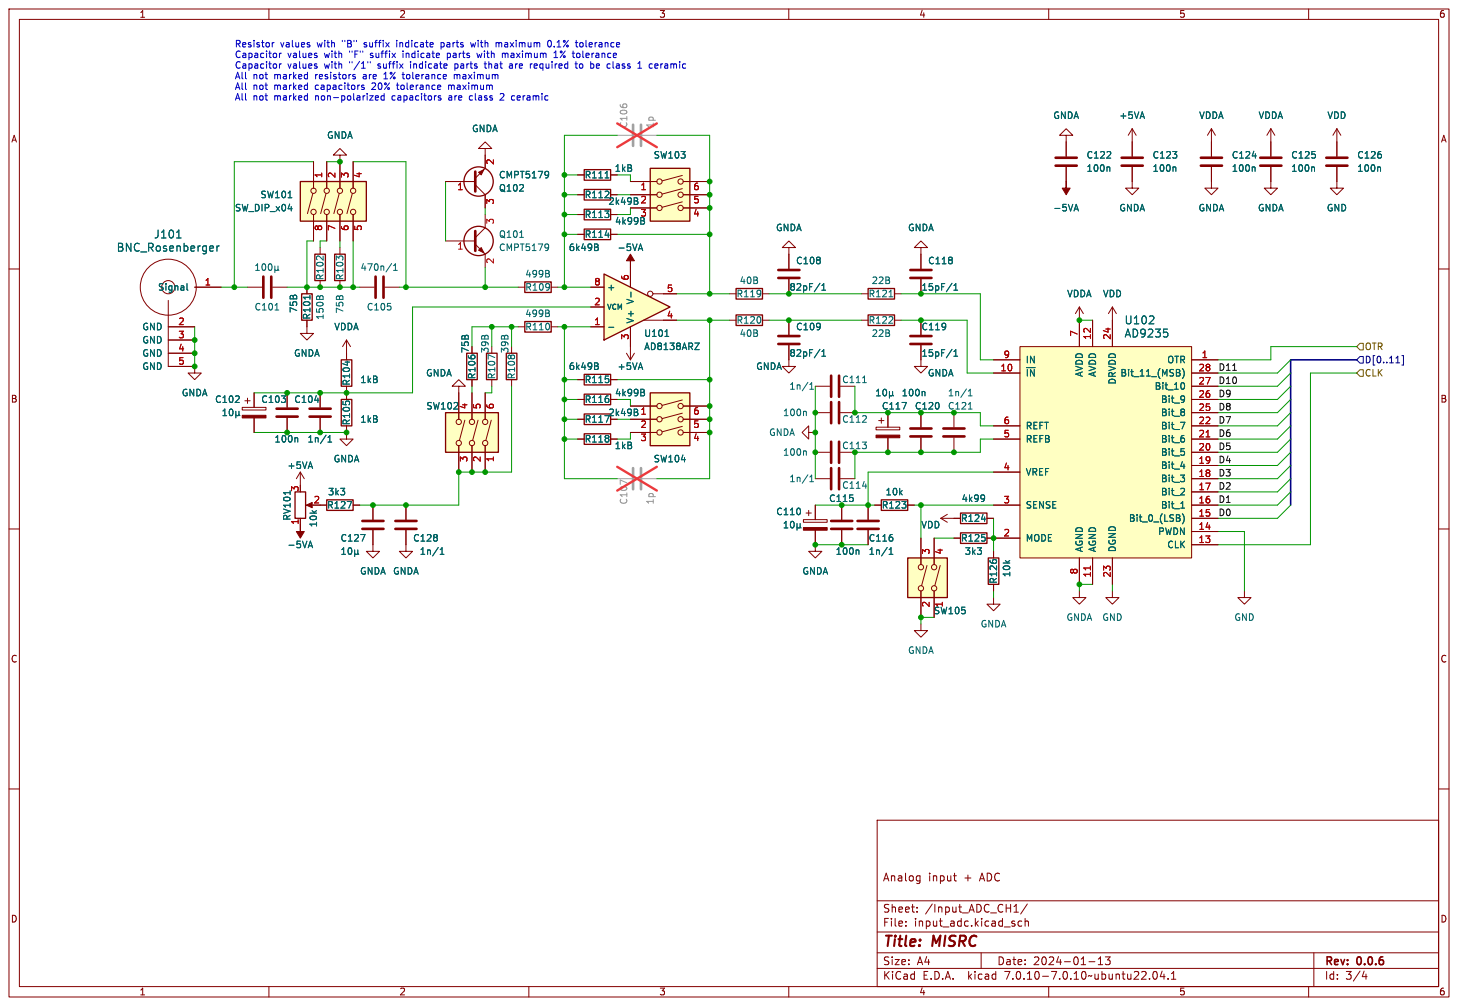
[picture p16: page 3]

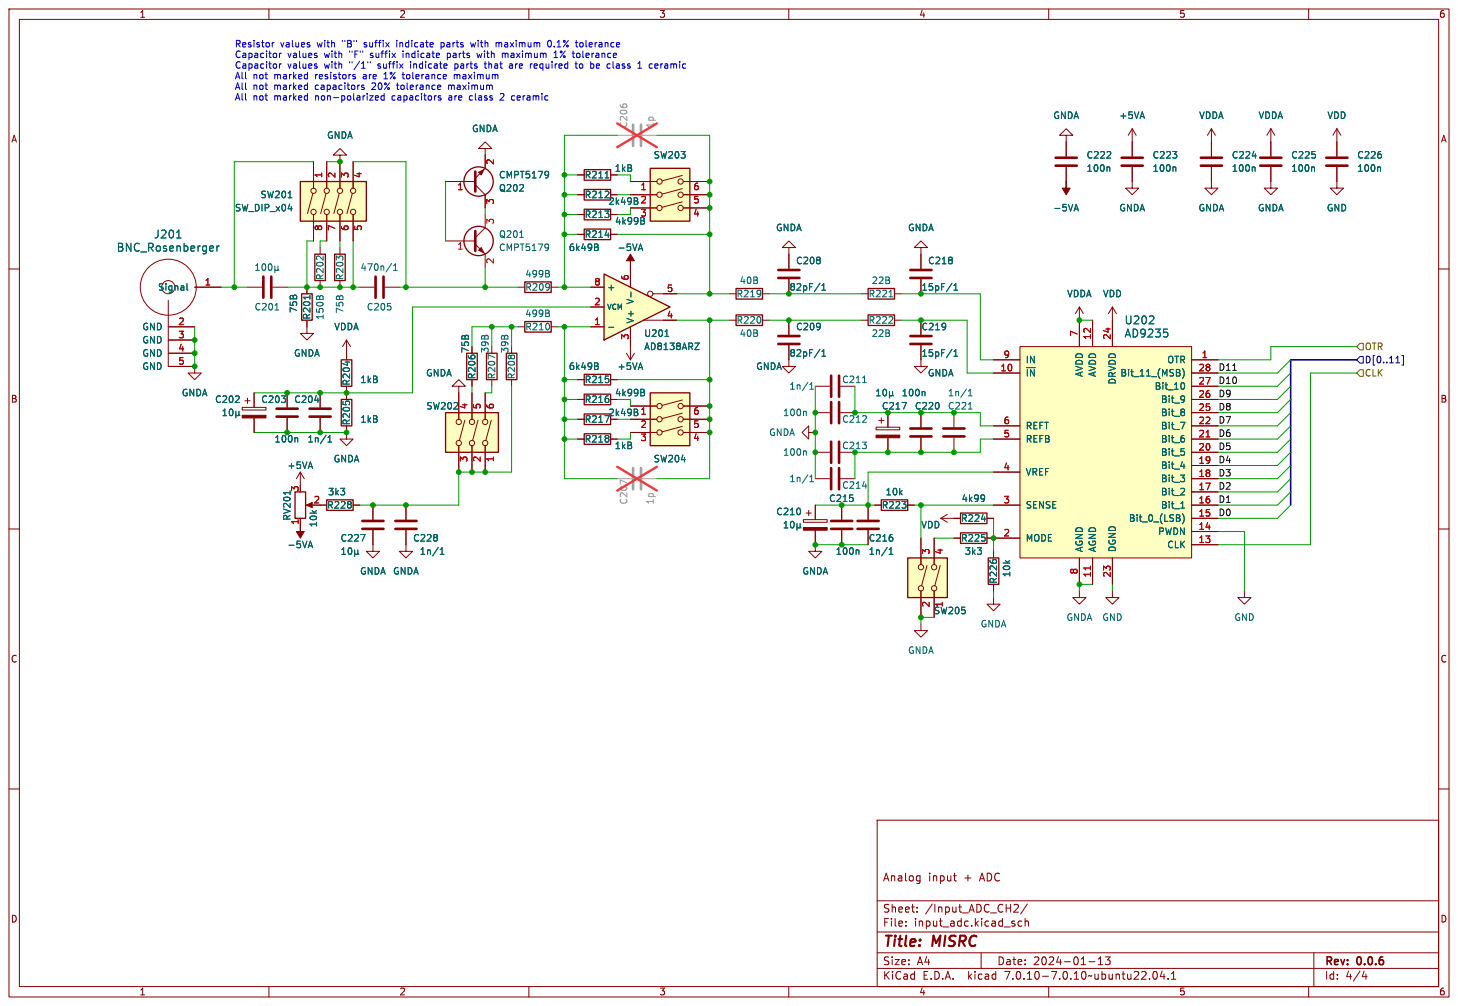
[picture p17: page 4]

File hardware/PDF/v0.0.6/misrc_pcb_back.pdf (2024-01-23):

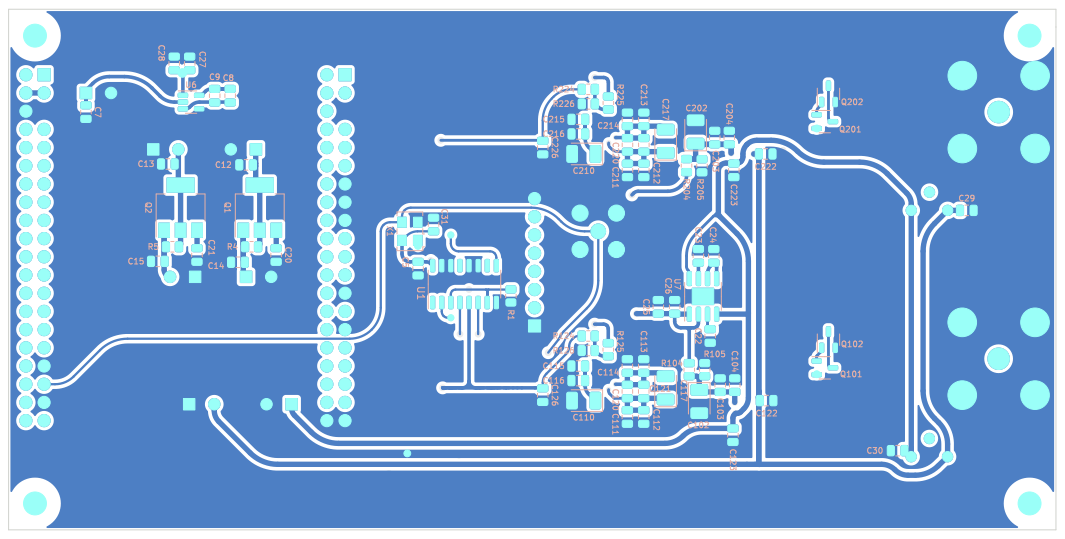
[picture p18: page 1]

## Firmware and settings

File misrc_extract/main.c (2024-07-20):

/*
* MISRC extract
* Copyright (C) 2024  vrunk11, stefan_o
*
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
* You should have received a copy of the GNU General Public License
* along with this program.  If not, see <http://www.gnu.org/licenses/>.
*/

#include <errno.h>
#include <string.h>
#include <stdio.h>
#include <stdlib.h>
#include <math.h>
#include <stdint.h>

#ifndef _WIN32
	#include <getopt.h>
	#define aligned_free(x) free(x)
	#define PERF_MEASURE 0
#else
	#include <windows.h>
	#include <io.h>
	#include <fcntl.h>
	#include "getopt/getopt.h"
	#define aligned_free(x) _aligned_free(x)
	#define aligned_alloc(a,s) _aligned_malloc(s,a)
	#define PERF_MEASURE 0
#endif


#if PERF_MEASURE
#include <time.h>
#endif

#define VERSION "0.3"
#define COPYRIGHT "licensed under GNU GPL v3 or later, (c) 2024 vrunk11, stefan_o"

#define BUFFER_SIZE 65536*32

#define _FILE_OFFSET_BITS 64

void usage(void)
{
	fprintf(stderr,
		"A simple program for extracting captured data into separate files\n\n"
		"Usage:\n"
		"\t[-i input file (use '-' to read from stdin)]\n"
		"\t[-a ADC A output file (use '-' to write on stdout)]\n"
		"\t[-b ADC B output file (use '-' to write on stdout)]\n"
		"\t[-x AUX output file (use '-' to write on stdout)]\n"
		"\t[-p pad lower 4 bits of 16 bit output with 0 instead of upper 4]\n"
		"\t[-s input is captured as single channel (-b cannot be used)]\n"
	);
	exit(1);
}

//bit masking
#define MASK_1      0xFFF
#define MASK_2      0xFFF00000
#define MASK_AUX    0xFF000
#define MASK_AUXS   0xF000

void extract_S_C(uint16_t *in, size_t len, size_t *clip, uint8_t *aux, int16_t *outA, int16_t *outB) {
	for(size_t i = 0; i < len; i++)
	{
		outA[i]  = 2048 - ((int16_t)(in[i] & MASK_1));
		aux[i]   = (in[i] & MASK_AUXS) >> 12;
		clip[0] += ((in[i] >> 12) & 1);
	}
}

void extract_A_C(uint32_t *in, size_t len, size_t *clip, uint8_t *aux, int16_t *outA, int16_t *outB) {
	for(size_t i = 0; i < len; i++)
	{
		outA[i]  = 2048 - ((int16_t)(in[i] & MASK_1));
		aux[i]   = (in[i] & MASK_AUX) >> 12;
		clip[0] += ((in[i] >> 12) & 1);
	}
}

void extract_B_C(uint32_t *in, size_t len, size_t *clip, uint8_t *aux, int16_t *outA, int16_t *outB) {
	for(size_t i = 0; i < len; i++)
	{
		outB[i]  = 2048 - ((int16_t)((in[i] & MASK_2) >> 20));
		aux[i]   = (in[i] & MASK_AUX) >> 12;
		clip[1] += ((in[i] >> 13) & 1);
	}
}

void extract_AB_C(uint32_t *in, size_t len, size_t *clip, uint8_t *aux, int16_t *outA, int16_t *outB) {
	for(size_t i = 0; i < len; i++)
	{
		outA[i]  = 2048 - ((int16_t)(in[i] & MASK_1));
		outB[i]  = 2048 - ((int16_t)((in[i] & MASK_2) >> 20));
		aux[i]   = (in[i] & MASK_AUX) >> 12;
		clip[0] += ((in[i] >> 12) & 1);
		clip[1] += ((in[i] >> 13) & 1);
	}
}

void extract_S_p_C(uint16_t *in, size_t len, size_t *clip, uint8_t *aux, int16_t *outA, int16_t *outB) {
	for(size_t i = 0; i < len; i++)
	{
		outA[i]  = (2048 - ((int16_t)(in[i] & MASK_1)))<<4;
		aux[i]   = (in[i] & MASK_AUXS) >> 12;
		clip[0] += ((in[i] >> 12) & 1);
	}
}

void extract_A_p_C(uint32_t *in, size_t len, size_t *clip, uint8_t *aux, int16_t *outA, int16_t *outB) {
	for(size_t i = 0; i < len; i++)
	{
		outA[i]  = (2048 - ((int16_t)(in[i] & MASK_1)))<<4;
		aux[i]   = (in[i] & MASK_AUX) >> 12;
		clip[0] += ((in[i] >> 12) & 1);
	}
}
void extract_B_p_C(uint32_t *in, size_t len, size_t *clip, uint8_t *aux, int16_t *outA, int16_t *outB) {
	for(size_t i = 0; i < len; i++)
	{
		outB[i]  = (2048 - ((int16_t)((in[i] & MASK_2) >> 20)))<<4;
		aux[i]   = (in[i] & MASK_AUX) >> 12;
		clip[1] += ((in[i] >> 13) & 1);
	}
}

void extract_AB_p_C(uint32_t *in, size_t len, size_t *clip, uint8_t *aux, int16_t *outA, int16_t *outB) {
	for(size_t i = 0; i < len; i++)
	{
		outA[i]  = (2048 - ((int16_t)(in[i] & MASK_1)))<<4;
		outB[i]  = (2048 - ((int16_t)((in[i] & MASK_2) >> 20)))<<4;
		aux[i]   = (in[i] & MASK_AUX) >> 12;
		clip[0] += ((in[i] >> 12) & 1);
		clip[1] += ((in[i] >> 13) & 1);
	}
}

#if defined(__x86_64__) || defined(_M_X64)
void extract_A_sse   (uint32_t *in, size_t len, size_t *clip, uint8_t *aux, int16_t *outA, int16_t *outB);
void extract_B_sse   (uint32_t *in, size_t len, size_t *clip, uint8_t *aux, int16_t *outA, int16_t *outB);
void extract_AB_sse  (uint32_t *in, size_t len, size_t *clip, uint8_t *aux, int16_t *outA, int16_t *outB);
void extract_S_sse   (uint16_t *in, size_t len, size_t *clip, uint8_t *aux, int16_t *outA, int16_t *outB);
void extract_A_p_sse (uint32_t *in, size_t len, size_t *clip, uint8_t *aux, int16_t *outA, int16_t *outB);
void extract_B_p_sse (uint32_t *in, size_t len, size_t *clip, uint8_t *aux, int16_t *outA, int16_t *outB);
void extract_AB_p_sse(uint32_t *in, size_t len, size_t *clip, uint8_t *aux, int16_t *outA, int16_t *outB);
void extract_S_p_sse (uint16_t *in, size_t len, size_t *clip, uint8_t *aux, int16_t *outA, int16_t *outB);
int check_cpu_feat();
#endif

int main(int argc, char **argv)
{
//set pipe mode to binary in windows
#if defined(_WIN32) || defined(_WIN64)
	_setmode(_fileno(stdout), O_BINARY);
	_setmode(_fileno(stdin), O_BINARY);
#endif

	int opt, pad=0, single=0;


	//file adress
	char *input_name_1    = NULL;
	char *output_name_1   = NULL;
	char *output_name_2   = NULL;
	char *output_name_aux = NULL;
	
	//input file
	FILE *input_1;
	
	//output files
	FILE *output_1;
	FILE *output_2;
	FILE *output_aux;
	
	//buffer
	uint32_t *buf_tmp = aligned_alloc(16,sizeof(uint32_t)*BUFFER_SIZE);
	int16_t  *buf_1   = aligned_alloc(16,sizeof(int16_t) *BUFFER_SIZE);
	int16_t  *buf_2   = aligned_alloc(16,sizeof(int16_t) *BUFFER_SIZE);
	uint8_t  *buf_aux = aligned_alloc(16,sizeof(uint8_t) *BUFFER_SIZE);
	
	//number of byte read
	int nb_block;
	
	//clipping state
	size_t clip[2] = {0, 0};
	
	// conversion function
	void (*conv_function)(uint32_t *in, size_t len, size_t *clip, uint8_t *aux, int16_t *outA, int16_t *outB);

#if PERF_MEASURE
	struct timespec start, stop;
	double timeread = 0.0, timeconv = 0.0, timewrite = 0.0;
#endif

	fprintf(stderr,
		"MISRC extract " VERSION "\n"
		COPYRIGHT "\n\n"
	);

	while ((opt = getopt(argc, argv, "i:a:b:x:psh")) != -1) {
		switch (opt) {
		case 'i':
			input_name_1 = optarg;
			break;
		case 'a':
			output_name_1 = optarg;
			break;
		case 'b':
			output_name_2 = optarg;
			break;
		case 'x':
			output_name_aux = optarg;
			break;
		case 'p':
			pad = 1;
			break;
		case 's':
			single = 1;
			break;
		case 'h':
		default:
			usage();
			break;
		}
	}
	
	if((input_name_1 == NULL || (output_name_1 == NULL && output_name_2 == NULL && output_name_aux == NULL))
		|| (single == 1 && output_name_2 != NULL))
	{
		usage();
	}
	
	//reading file 1
	if(input_name_1 != NULL)
	{
		if (strcmp(input_name_1, "-") == 0)// Read samples from stdin
		{
			input_1 = stdin;
		}
		else 
		{
			input_1 = fopen(input_name_1, "rb");
			if (!input_1) {
				fprintf(stderr, "(1) : Failed to open %s\n", input_name_1);
				return -ENOENT;
			}
		}
	}
	
	if(output_name_1 != NULL)
	{
		//opening output file 1
		if (strcmp(output_name_1, "-") == 0)// Read samples from stdin
		{
			output_1 = stdout;
		}
		else
		{
			output_1 = fopen(output_name_1, "wb");
			if (!output_1) {
				fprintf(stderr, "(2) : Failed to open %s\n", output_name_1);
				return -ENOENT;
			}
		}
	}
	
	if(output_name_2 != NULL)
	{
		//opening output file 2
		if (strcmp(output_name_2, "-") == 0)// Read samples from stdin
		{
			output_2 = stdout;
		}
		else if(output_name_2 != NULL)
		{
			output_2 = fopen(output_name_2, "wb");
			if (!output_2) {
				fprintf(stderr, "(2) : Failed to open %s\n", output_name_2);
				return -ENOENT;
			}
		}
	}
	
	if(output_name_aux != NULL)
	{
		//opening output file aux
		if (strcmp(output_name_aux, "-") == 0)// Read samples from stdin
		{
			output_aux = stdout;
		}
		else if(output_name_aux != NULL)
		{
			output_aux = fopen(output_name_aux, "wb");
			if (!output_aux) {
				fprintf(stderr, "(2) : Failed to open %s\n", output_name_aux);
				return -ENOENT;
			}
		}
	}
#if defined(__x86_64__) || defined(_M_X64)
	if(check_cpu_feat()==0) {
		fprintf(stderr,"Detected processor with SSSE3 and POPCNT, using optimized extraction routine\n\n");
		if (pad==1) {
			if (single == 1) conv_function = (void (*)(uint32_t*, size_t, size_t*, uint8_t*, int16_t*, int16_t*)) &extract_S_p_sse;
			else if (output_name_1 == NULL) conv_function = &extract_B_p_sse;
			else if (output_name_2 == NULL) conv_function = &extract_A_p_sse;
			else conv_function = &extract_AB_p_sse;
		}
		else {
			if (single == 1) conv_function = (void (*)(uint32_t*, size_t, size_t*, uint8_t*, int16_t*, int16_t*)) &extract_S_sse;
			else if (output_name_1 == NULL) conv_function = &extract_B_sse;
			else if (output_name_2 == NULL) conv_function = &extract_A_sse;
			else conv_function = &extract_AB_sse;
		}
	}
	else {
		fprintf(stderr,"Detected processor without SSSE3 and POPCNT, using standard extraction routine\n\n");
#endif
		if (pad==1) {
			if (single == 1) conv_function = (void (*)(uint32_t*, size_t, size_t*, uint8_t*, int16_t*, int16_t*)) &extract_S_p_C;
			else if (output_name_1 == NULL) conv_function = &extract_B_p_C;
			else if (output_name_2 == NULL) conv_function = &extract_A_p_C;
			else conv_function = &extract_AB_p_C;
		}
		else {
			if (single == 1) conv_function = (void (*)(uint32_t*, size_t, size_t*, uint8_t*, int16_t*, int16_t*)) &extract_S_C;
			else if (output_name_1 == NULL) conv_function = &extract_B_C;
			else if (output_name_2 == NULL) conv_function = &extract_A_C;
			else conv_function = &extract_AB_C;
		}
#if defined(__x86_64__) || defined(_M_X64)
	}
#endif
	
	if(input_name_1 != NULL && (output_name_1 != NULL || output_name_2 != NULL || output_name_aux != NULL))
	{
		while(!feof(input_1))
		{
#if PERF_MEASURE
			clock_gettime(CLOCK_MONOTONIC, &start);
#endif

			nb_block = fread(buf_tmp,4>>single,BUFFER_SIZE,input_1);

#if PERF_MEASURE
			clock_gettime(CLOCK_MONOTONIC, &stop);
			timeread += (stop.tv_sec - start.tv_sec) * 1e6 + (stop.tv_nsec - start.tv_nsec) / 1e3;
			clock_gettime(CLOCK_PROCESS_CPUTIME_ID, &start);
#endif

			conv_function(buf_tmp, nb_block, clip, buf_aux, buf_1, buf_2);

#if PERF_MEASURE
			clock_gettime(CLOCK_PROCESS_CPUTIME_ID, &stop);
			timeconv += (stop.tv_sec - start.tv_sec) * 1e6 + (stop.tv_nsec - start.tv_nsec) / 1e3;
#endif

			if(clip[0] > 0)
			{
				fprintf(stderr,"ADC A : %ld samples clipped\n",clip[0]);
				clip[0] = 0; 
			}
			
			if(clip[1] > 0)
			{
				fprintf(stderr,"ADC B : %ld samples clipped\n",clip[1]);
				clip[1] = 0; 
			}
#if PERF_MEASURE
			clock_gettime(CLOCK_MONOTONIC, &start);
#endif
			//write output
			if(output_name_1   != NULL){fwrite(buf_1, 2,nb_block,output_1);}
			if(output_name_2   != NULL){fwrite(buf_2, 2,nb_block,output_2);}
			if(output_name_aux != NULL){fwrite(buf_aux,1,nb_block,output_aux);}

#if PERF_MEASURE
			clock_gettime(CLOCK_MONOTONIC, &stop);
			timewrite += (stop.tv_sec - start.tv_sec) * 1e6 + (stop.tv_nsec - start.tv_nsec) / 1e3;
#endif
		}
	}

////ending of the program
	
	aligned_free(buf_1);
	aligned_free(buf_2);
	aligned_free(buf_aux);
	
	//Close file 1
	if(input_name_1 != NULL)
	{
		if (input_1 && (input_1 != stdin))
		{
			fclose(input_1);
		}
	}
	
	if(output_name_1 != NULL)
	{
		//Close out file
		if (output_1 && (output_1 != stdout))
		{
			fclose(output_1);
		}
	}
	
	if(output_name_2 != NULL)
	{
		if (output_2 && (output_2 != stdout))
		{
			fclose(output_2);
		}
	}
	
	if(output_name_aux != NULL)
	{
		if (output_aux && (output_aux != stdout))
		{
			fclose(output_aux);
		}
	}

#if PERF_MEASURE
	fprintf(stderr, "Readtime: %f\nConvtime: %f\nwrittime: %f\n", timeread, timeconv, timewrite);
#endif

	return 0;
}

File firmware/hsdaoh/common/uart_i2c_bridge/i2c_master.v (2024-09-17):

// Tiny but mighty I2C master
// Copyright (c) 2021-2024  Artin Isagholian <artinisagholian@gmail.com>
// https://github.com/0xArt/Tiny_But_Mighty_I2C_Master_Verilog
// License: GPL V3.0
//
// converted to Verilog and extended with the 'got_acknowledge' output for hsdaoh

module i2c_master (
	clock,
	reset_n,
	enable,
	read_write,
	mosi_data,
	register_address,
	device_address,
	divider,
	miso_data,
	busy,
    got_acknowledge,
	external_serial_data,
	external_serial_clock
);

localparam S_IDLE                  =   0;
localparam S_START                 =   1;
localparam S_WRITE_ADDR_W          =   2;
localparam S_CHECK_ACK             =   3;
localparam S_WRITE_REG_ADDR        =   4;
localparam S_RESTART               =   5;
localparam S_WRITE_ADDR_R          =   6;
localparam S_READ_REG              =   7;
localparam S_SEND_NACK             =   8;
localparam S_SEND_STOP             =   9;
localparam S_WRITE_REG_DATA        =   10;
localparam S_WRITE_REG_ADDR_MSB    =   11;
localparam S_WRITE_REG_DATA_MSB    =   12;
localparam S_READ_REG_MSB          =   13;
localparam S_SEND_ACK              =   14;

	parameter DATA_WIDTH = 8;
	parameter REGISTER_WIDTH = 8;
	parameter ADDRESS_WIDTH = 7;
	input wire clock;
	input wire reset_n;
	input wire enable;
	input wire read_write;
	input wire [DATA_WIDTH - 1:0] mosi_data;
	input wire [REGISTER_WIDTH - 1:0] register_address;
	input wire [ADDRESS_WIDTH - 1:0] device_address;
	input wire [15:0] divider;
	output reg [DATA_WIDTH - 1:0] miso_data;
	output reg busy;
    output reg got_acknowledge;
	inout external_serial_data;
	inout external_serial_clock;
	reg [3:0] state;
	reg [3:0] _state;
	reg [3:0] post_state;
	reg [3:0] _post_state;
	reg serial_clock;
	reg _serial_clock;
	reg [ADDRESS_WIDTH:0] saved_device_address;
	reg [ADDRESS_WIDTH:0] _saved_device_address;
	reg [REGISTER_WIDTH - 1:0] saved_register_address;
	reg [REGISTER_WIDTH - 1:0] _saved_register_address;
	reg [DATA_WIDTH - 1:0] saved_mosi_data;
	reg [DATA_WIDTH - 1:0] _saved_mosi_data;
	reg [1:0] process_counter;
	reg [1:0] _process_counter;
	reg [7:0] bit_counter;
	reg [7:0] _bit_counter;
	reg serial_data;
	reg _serial_data;
	reg post_serial_data;
	reg _post_serial_data;
	reg last_acknowledge;
	reg _last_acknowledge;
	reg _saved_read_write;
	reg saved_read_write;
	reg [15:0] divider_counter;
	reg [15:0] _divider_counter;
	reg divider_tick;
	reg [DATA_WIDTH - 1:0] _miso_data;
	reg _busy;
    reg _got_acknowledge;
	reg serial_data_output_enable;
	reg serial_clock_output_enable;
	assign external_serial_clock = (serial_clock_output_enable ? serial_clock : 1'bz);
	assign external_serial_data = (serial_data_output_enable ? serial_data : 1'bz);
	always @(*) begin
		_state = state;
		_post_state = post_state;
		_process_counter = process_counter;
		_bit_counter = bit_counter;
		_last_acknowledge = last_acknowledge;
		_miso_data = miso_data;
		_saved_read_write = saved_read_write;
		_busy = busy;
        _got_acknowledge = got_acknowledge;
		_divider_counter = divider_counter;
		_saved_register_address = saved_register_address;
		_saved_device_address = saved_device_address;
		_saved_mosi_data = saved_mosi_data;
		_serial_data = serial_data;
		_serial_clock = serial_clock;
		_post_serial_data = post_serial_data;
		if (divider_counter == divider) begin
			_divider_counter = 0;
			divider_tick = 1;
		end
		else begin
			_divider_counter = divider_counter + 1;
			divider_tick = 0;
		end
		if ((((state != S_IDLE) && (state != S_CHECK_ACK)) && (state != S_READ_REG)) && (state != S_READ_REG_MSB))
			serial_data_output_enable = 1;
		else
			serial_data_output_enable = 0;
		if (((state != S_IDLE) && (process_counter != 1)) && (process_counter != 2))
			serial_clock_output_enable = 1;
		else
			serial_clock_output_enable = 0;
		case (state)
			S_IDLE: begin
				_process_counter = 0;
				_bit_counter = 0;
				_last_acknowledge = 0;
				_busy = 0;
				_saved_read_write = read_write;
				_saved_register_address = register_address;
				_saved_device_address = {device_address, 1'b0};
				_saved_mosi_data = mosi_data;
				_serial_data = 1;
				_serial_clock = 1;
				if (enable) begin
                    _got_acknowledge = 0; 
					_state = S_START;
					_post_state = S_WRITE_ADDR_W;
					_busy = 1;
				end
			end
			S_START:
				if (divider_tick)
					case (process_counter)
						0: _process_counter = 1;
						1: begin
							_serial_data = 0;
							_process_counter = 2;
						end
						2: begin
							_bit_counter = 8;
							_process_counter = 3;
						end
						3: begin
							_serial_clock = 0;
							_process_counter = 0;
							_state = post_state;
							_serial_data = saved_device_address[ADDRESS_WIDTH];
						end
					endcase
			S_WRITE_ADDR_W:
				if (divider_tick)
					case (process_counter)
						0: begin
							_serial_clock = 1;
							_process_counter = 1;
						end
						1:
							if (external_serial_clock == 1)
								_process_counter = 2;
						2: begin
							_serial_clock = 0;
							_bit_counter = bit_counter - 1;
							_process_counter = 3;
						end
						3: begin
							if (bit_counter == 0) begin
								_post_serial_data = saved_register_address[REGISTER_WIDTH - 1];
								if (REGISTER_WIDTH == 16)
									_post_state = S_WRITE_REG_ADDR_MSB;
								else
									_post_state = S_WRITE_REG_ADDR;
								_state = S_CHECK_ACK;
								_bit_counter = 8;
							end
							else
								_serial_data = saved_device_address[bit_counter - 1];
							_process_counter = 0;
						end
					endcase
			S_CHECK_ACK:
				if (divider_tick)
					case (process_counter)
						0: begin
							_serial_clock = 1;
							_process_counter = 1;
						end
						1:
							if (external_serial_clock == 1) begin
								_last_acknowledge = 0;
								_process_counter = 2;
							end
						2: begin
							_serial_clock = 0;
							if (external_serial_data == 0)
								_last_acknowledge = 1;
							_process_counter = 3;
						end
						3: begin
							if (last_acknowledge == 1) begin
                                _got_acknowledge = 1;
								_last_acknowledge = 0;
								_serial_data = post_serial_data;
								_state = post_state;
							end
							else begin
                                _got_acknowledge = 0;
								_state = S_SEND_STOP;
                            end
							_process_counter = 0;
						end
					endcase
			S_WRITE_REG_ADDR_MSB:
				if (divider_tick)
					case (process_counter)
						0: begin
							_serial_clock = 1;
							_process_counter = 1;
						end
						1:
							if (external_serial_clock == 1) begin
								_last_acknowledge = 0;
								_process_counter = 2;
							end
						2: begin
							_serial_clock = 0;
							_bit_counter = bit_counter - 1;
							_process_counter = 3;
						end
						3: begin
							if (bit_counter == 0) begin
								_post_state = S_WRITE_REG_ADDR;
								_post_serial_data = saved_register_address[7];
								_bit_counter = 8;
								_serial_data = 0;
								_state = S_CHECK_ACK;
							end
							else
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

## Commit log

2024-01-13 Hardware rev 0.0.5
    [input_adc.kicad_sch, misrc.kicad_pcb, misrc.kicad_sch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]
2024-01-13 new hardware revision
    [input_adc.kicad_sch, misrc.kicad_pcb, misrc.kicad_sch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]
2024-01-23 Updated annonation on the PCB, added gerbers, PDFs and BOM
    [input_adc.kicad_sch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]
2024-01-26 check for AMD64/x86_64/x64 architecture for assembly to allow builds on other architectures
2024-02-28 Manually install nasm on Windows
    Fixes upstream issue with winget
2024-07-20 Fix flipped conditions on argument check
    [main.c]
2024-09-17 Added adapter board for Tang Nano 20K, prepared misrc_extract for new tools
    [fx3_tn20k_adapter-B_Cu.gbr, fx3_tn20k_adapter-B_Mask.gbr, fx3_tn20k_adapter-B_Silkscreen.gbr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]
2024-10-09 add v1.5 version and restructure
    [MISRC V1.5.kicad_pcb, MISRC V1.5.kicad_pcb_bom.csv, MISRC V1.5.kicad_pcb_bom.xlsx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]
2024-10-14 Update for current MS2130 / Tang Nano use and v1.5 image
2024-10-14 progress display and flac seektable in misrc_capture, some cleanups
    [MISRC V1.5.kicad_pcb_bom.csv, MISRC V1.5.kicad_pcb_bom.xlsx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]
2024-10-23 some fixes for single-channel capture
    [misrc_capture.c]
2024-10-25 misrc_capture support for non-Linux POSIX platforms, reduced hsdaoh framerate
2024-10-29 fix messages during capture, thread join fix
    [misrc_capture.c]
2024-10-31 only channel b fix
    [misrc_capture.c]
2024-11-05 Fix image so actually shown, update readme and image to show new Tang Nano 20k with adapter PCB.
2025-01-14 Update windows driver usage, and MS2130 link
2025-01-15 Add - spacer
2025-02-05 V1.5a production changes, change crystal to one with higher load abbilitys
    [MISRC V1.5.kicad_pcb_bom.csv, MISRC V1.5.kicad_pcb_bom.xlsx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]
2025-02-05 Update BOM
    [MISRC V1.5.kicad_pcb_bom.xlsx]
2025-02-05 Update Amphenol SMA to generic SMA (901-144-8RFX is not in common cable use)
    [MISRC V1.5.kicad_pcb_bom.csv, MISRC V1.5.kicad_pcb_bom.xlsx]
2025-02-06 update production files
    [misrc-B_Cu.gbr, misrc-B_Mask.gbr, misrc-B_Paste.gbr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]
2025-02-26 Fix V1.5a gerbers
    [MISRC_v1.5-B_Cu.gbr, MISRC_v1.5-B_Mask.gbr, MISRC_v1.5-B_Paste.gbr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]
2025-03-04 Cleanup of v1.5 and v1.5a versions
    [MISRC V1.5.kicad_pcb_bom.xlsx, input_adc.kicad_sch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]
2025-03-05 silkscreen positions
    [misrc_v1.5a.kicad_pcb]
2025-03-07 Fix J201 pad path, causing production issues with fabs
    [misrc_v1.5.kicad_pcb, misrc_v1.5a.kicad_pcb]
2025-04-25 Update misrc_capture.c
    Added new options A, B, w, and t. Fixed option n that didn't work. Options A and B suppress clipping messages for their ADC. Option w forces an overwrite of files without asking. Option t multiples the number entered by 40 million (so the user can enter the number of seconds to capture). Option n now captures only the number of samples entered.
    [misrc_capture.c]
2025-05-13 fix possible div by 0 in core count detection
    [misrc_capture.c]
2025-05-24 fixed usage of the word driver
2025-07-21 Fixed compiler warnings, build fixes
    [misrc_capture.c, misrc_extract.c]
2025-07-25 windows arm build fix
2025-08-04 overwrite question fix and cleanup, fix aux only output
    [misrc_capture.c]
2025-08-09 new misrc hardware
    [CONSMA002-L-G.step, DOSIN-BNC_F102-243.stp, KLP42X-61-WW-RR_rA7.IGS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]
2025-08-15 fix windows build issue, fix ffmpeg not build on non-Windows platforms
    [misrc_capture.c]
2025-09-30 repositioning of parts for more case options
    [audio_adc.kicad_sch, input_adc.kicad_sch, input_adc_CH2.kicad_sch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]
2025-10-01 minor hardware changes
    [misrc_v2.5.kicad_sch]
2025-10-03 schematic layout cleanups, silkscreen optimzation on PCB, slightly moved clock connector
    [audio_adc.kicad_sch, input_adc.kicad_sch, input_adc_CH2.kicad_sch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]
2025-10-06 fixed switch orientation, impedance resistors
    [misrc_v2.5.kicad_sch]
2025-10-07 optimized switch position
2025-10-07 moved clock and aux connector to the back side
    [misrc_v2.5.kicad_sch]
2025-10-08 moved clipping LEDs to front, replaced reset switch with delay
    [misrc_v2.5.kicad_sch]
2025-10-09 Silkscreen updates
    [audio_adc.kicad_sch, input_adc.kicad_sch, input_adc_CH2.kicad_sch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]
2025-10-09 fixed resistor value
    [misrc_v2.5.kicad_sch]
2025-10-10 BOM adjustments
    [misrc_v2.5.kicad_sch]
2025-10-10 updated LED footprint
    [audio_adc.kicad_sch, input_adc_CH1.kicad_sch, input_adc_CH2.kicad_sch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]
2025-10-12 changed pot direction
    [audio_adc.kicad_sch, input_adc.kicad_sch, input_adc_CH1.kicad_sch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]
2025-10-15 updated bom
    [audio_adc.kicad_sch, input_adc.kicad_sch, input_adc_CH1.kicad_sch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]
2025-10-15 position fix, added 3d models
    [ECS-TXO-2520-33-400-AN-TR.STEP, RF2-49B-T-00-50-G-HDW.STEP, misrc_v2.5.kicad_sch]
2025-10-17 fixed clearance of a rounded trace
2025-10-17 Updated footprints, include font
2025-10-20 fixed adapter board connectors swapped
    [misrc_v2.5.kicad_sch]
2025-10-21 case panels, 3d model with case with panels
    [audio_adc.kicad_sch, fx3_tn20k_adapter.kicad_pcb, input_adc.kicad_sch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]
2025-10-22 back panel connector alignment, optimize 3d models
    [fx3_tn20k_adapter.kicad_pcb, misrc_v2.5_back_panel.step, misrc_v2.5_front_panel.step]
2025-10-22 case panel gerbers
    [misrc_v2.5_back_panel-B_Cu.gbr, misrc_v2.5_back_panel-B_Mask.gbr, misrc_v2.5_back_panel-B_Silkscreen.gbr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]
2025-10-23 optimized clock distribution
    [audio_adc.kicad_sch, input_adc.kicad_sch, input_adc_CH1.kicad_sch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]
2025-10-24 added ferrit beads to protect clock generation from DC switching noise
    [misrc_v2.5.kicad_sch]
2025-10-24 optimized some via placements
    [misrc_v2.5.kicad_sch]
2025-10-25 fixed font and some via placements
    [misrc_v2.5.kicad_sch]
2025-10-26 fixed zero adjust, more ferrit beads, silkscreen fixes
    [audio_adc.kicad_sch, input_adc.kicad_sch, input_adc_CH1.kicad_sch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]
2025-10-29 remove footprints of alternative connectors from the PCB
    [input_adc.kicad_sch, input_adc_CH1.kicad_sch]
2025-10-29 made BNC footprint symmetrical
2025-11-29 replaced swresample with libsoxr, more resampling options, fixed resampling and -p with flac
    [misrc_capture.c]
2025-11-29 fix to set sample rate in flac correctly
    [misrc_capture.c]
2025-11-29 fix build issues with new cmake
    [misrc_capture.c]
2026-01-04 minor cleanup, windows build fix, better thread naming
    [capture.c, misrc_capture.c]
2026-01-05 fixed command line parsing issue, progress display issue
    [misrc_capture.c]

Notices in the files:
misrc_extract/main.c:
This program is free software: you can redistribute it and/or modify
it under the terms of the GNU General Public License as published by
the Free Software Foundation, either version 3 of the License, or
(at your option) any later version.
